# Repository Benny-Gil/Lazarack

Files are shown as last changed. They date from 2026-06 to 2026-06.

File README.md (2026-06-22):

# lazarack

*Lazarus + rack* — **raise a dead laptop motherboard from the e-waste pile into a rack-mounted homelab server.**


&nbsp;
&nbsp;
&nbsp;
&nbsp;

A **3D-printable, highly-modular 1U case** that turns a salvaged laptop
motherboard into a unit you can rack-mount in a **10-inch "mini" server rack**.
It's **parametric** — set your board's outline in one block and the whole
chassis reflows, so it fits **any laptop board that fits a 10" rack** (the
**Dell Inspiron 15-5558 / 5559** is the worked example here). Modeled in
**OpenSCAD**; every part prints flat with no supports on a low-accuracy
**Creality Ender 3 V3 SE** (220 × 220 mm bed) in PETG.

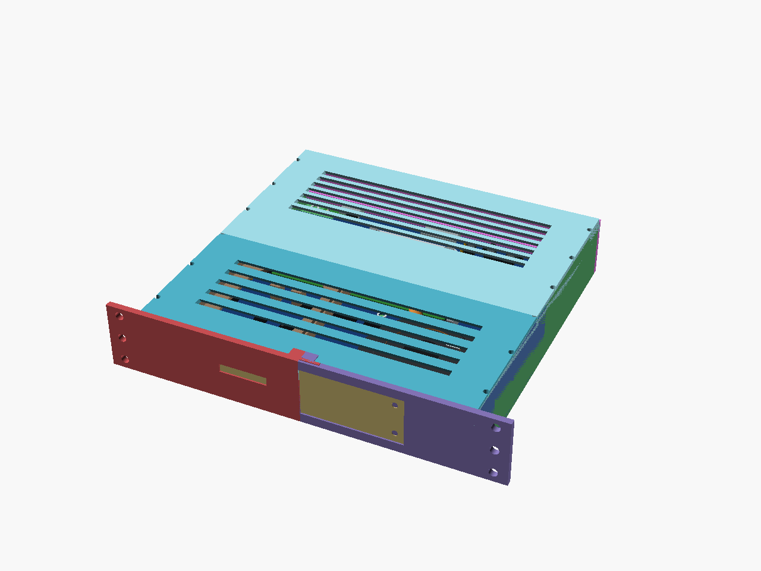
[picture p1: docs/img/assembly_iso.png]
Assembled, isometric


> ⚠️ **Work in progress.** The geometry is complete and renders/exports cleanly,
> but the board-specific dimensions in `parts/params.scad` are still **estimates
> tagged `// MEASURE`**. Caliper your board and update that one file before
> printing for real. See [Measuring your board](#measuring-your-board).

**Jump to:** [Design](#design-language--loose-fit-bolt-tight) · [Why](#why) · [How it goes together](#how-it-goes-together) · [Print it](#print-it) · [Build it](#build-it) · [Use it for another board](#use-it-for-a-different-board) · [Measuring your board](#measuring-your-board) · [License](#license)

---

## Design language — "loose-fit, bolt-tight"

This is a **Round-2 redesign** for a low-accuracy printer. The governing rule is
**LOOSE-FIT, BOLT-TIGHT**: nothing relies on a dimensionally accurate print to
mate. Every seam carries a `FIT_CLEARANCE` (0.5 mm) gap that absorbs print slop,
and **bolts pull the seams flush** rather than press-fit tolerances. Concretely:

- The baseplate is **four bed-friendly quadrants** bolted together by flat
  **seam-splice** bars across each seam — no tight interlocks to fight.
- The board is **not** held by fixed, dimensionally-critical standoffs. Instead
  it sits on **grid-placed `m25_grid_insert` standoffs** you drop onto the pilot
  grid wherever the board's holes land, and is trapped at the edges by
  **`board_edge_clip`** fingers. Slop in the print is taken up by the grid, not
  by a hole you have to hit exactly.
- Front `io_subplate` and `rear_panel` ship **blank** — you drill the actual
  port cutouts to your board after a test fit, so a misjudged dimension is a
  drill bit away, not a reprint.

---

## Why

A repurposed laptop motherboard makes a tidy, low-power homelab node — but it has
no chassis, odd mounting holes, split I/O, and (on this board) a **missing M.2
retention standoff**. This project wraps it in a bolt-together enclosure that
mounts to a [NiH DIY 10" cage-nut rack](https://www.printables.com/model/1634385-project-diy-10-server-rack)
and solves each of those problems with an independently-printable, swappable
module — none of which needs a precise print to work.

| Target | Detail |
|---|---|
| **Board** | Dell Inspiron 15-5558 / 5559 (Compal LA-B843P / LA-D071P), near-square ~203 × 197 mm |
| **Rack** | NiH "DIY 10-inch Server Rack" — EIA/ECA-310, **M5 cage nuts**, three 1U face holes per column |
| **Height** | **1U (44.45 mm)** — low-profile; board lies flat with its SODIMMs/blower under the lid |
| **Printer** | Ender 3 V3 SE (220 × 220 × 250 mm), low accuracy; every part ≤ ~190 mm/axis, flat, support-free |
| **Material** | PETG, 0.2 mm layer, 3–4 walls, 30–40 % infill |

---

## How it goes together

Everything bolts to **one shared 15 mm M3 self-tap pilot grid** on the
quadrant baseplate, so modules are independently printable, swappable, and
forgiving of print error.

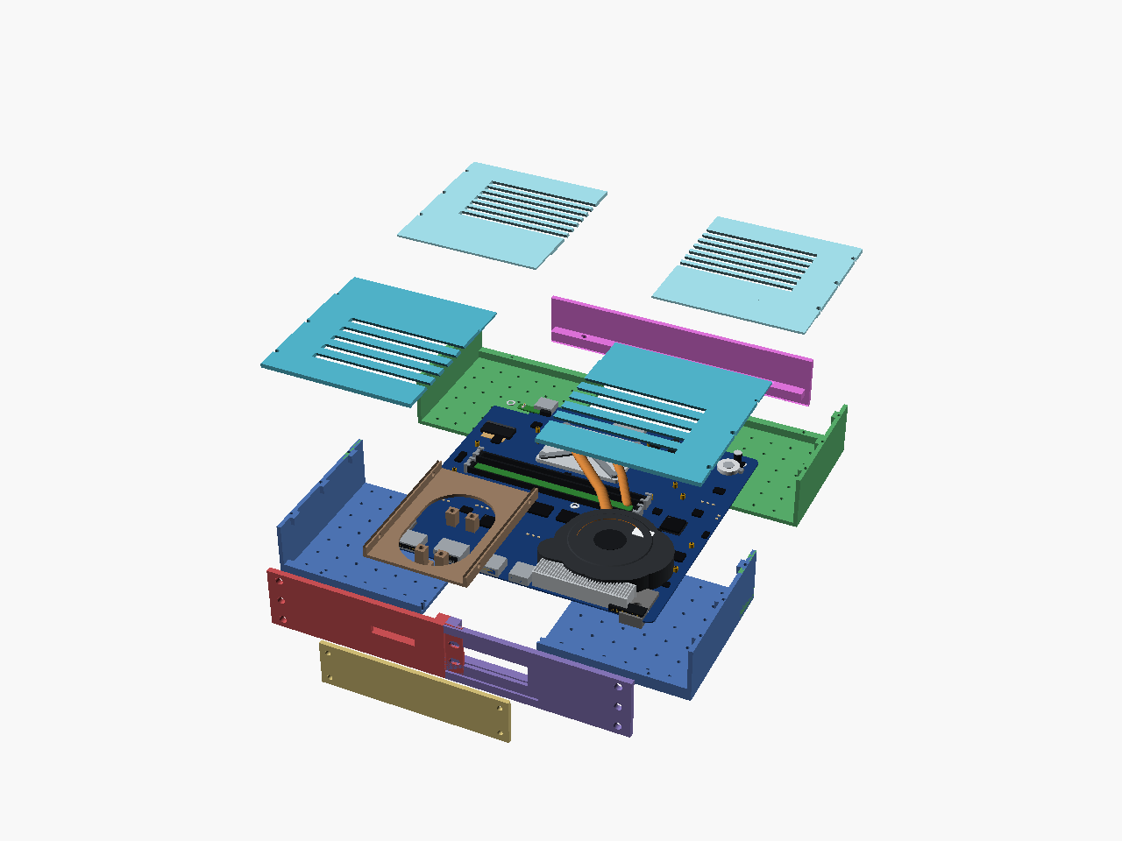
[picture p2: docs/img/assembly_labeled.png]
Exploded view with part legend


| # | Part | Role |
|---|---|---|
| 1–4 | `baseplate` → `baseplate_quad(qx,qy)` ×4 | Structural floor split into **four bed-friendly quadrants** with integral side walls; tied together by flat **`seam_splice`** bars bolted across the X and Y seams. Carries the 15 mm M3 self-tap pilot grid. |
| – | `seam_splice()` | Flat bridging bar that bolts across a quadrant seam into the grid (the "bolt-tight" half of the seam). |
| 5–6 | `faceplate_left` / `faceplate_right` | The 254 mm rack faceplate, split at the centerline (X=106) so each **M5 rack column stays whole on one tile**. Its bottom flange **rests on the front lip and bolts straight down** into shared self-tap pilots. |
| 7 | `io_subplate` | **Blank** swappable front insert with the 130 × 32 I/O window — you drill HDMI / USB-A / exhaust to your board after a fit check. |
| 8 | `m2_retainer` | Gusseted M2.5 post that **supplies the missing M.2 standoff**. |
| 9 | `rear_panel` | **Blank** rear panel — drill USB-C power-in / SD / audio later. Flange **rests on the rear lip and bolts into the shared pilots**. |
| 10 | `ssd_mezzanine` *(opt)* | 2.5" SATA drive carrier on stilts **above** the board, bolted to the grid. |
| 11–14 | `lid` → `lid_front(qx)` / `lid_rear(qx)` *(opt)* | Vented 1U top in **four bed-friendly tiles** (split in X *and* Y); each thumb-screws down into **wall-top self-tap bosses** on the baseplate. |
| – | `m25_grid_insert()` | Grid-dropped M2.5 board standoff (placed where the board holes land, not fixed). |
| – | `board_edge_clip()` | Finger that traps the board edge — board retention without a critical hole. |

With the lid off, the board drops onto grid-placed M2.5 standoffs, is trapped by
edge clips, and the I/O lines up behind the blank front subplate:

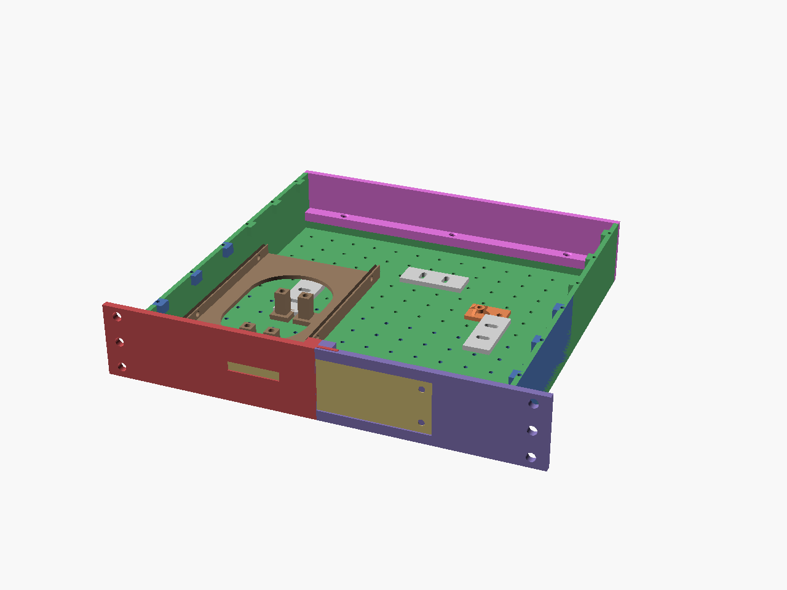
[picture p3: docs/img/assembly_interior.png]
Board mounted in the open chassis


The baseplate grid is **self-tapping pilot holes**, not a carpet of inserts —
you drive an M3 straight into the PETG only where a module (or standoff) lands:

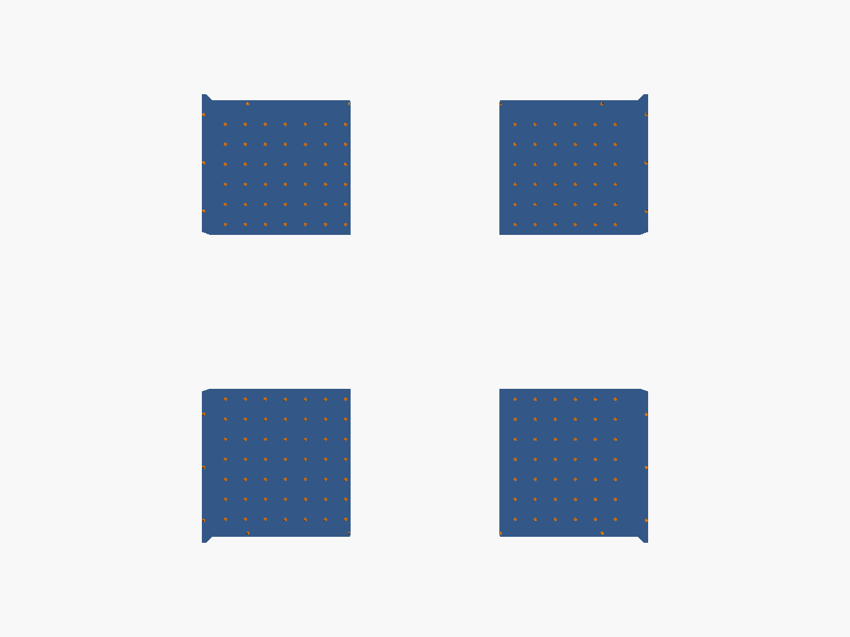
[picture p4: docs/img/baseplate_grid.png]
Baseplate self-tap pilot grid (one quadrant)


The four quadrants **butt together** and are tied by flat **`seam_splice`** bars
(red) that bolt into the grid on each side of a seam — slotted holes absorb
print slop, no interlock to fight:

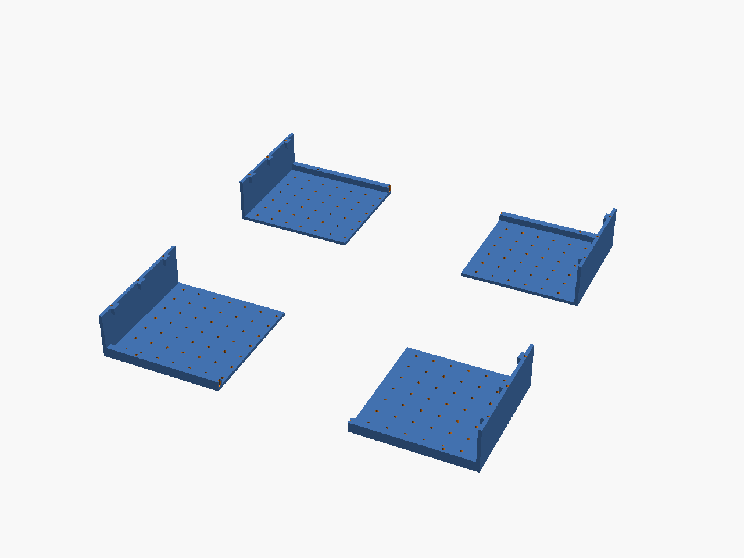
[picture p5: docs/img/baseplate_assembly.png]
Four baseplate quadrants joined by seam splices


Full mechanical spec, joinery, BOM, and print-plate layout: **[`CASE_DESIGN.md`](CASE_DESIGN.md)**.
Slicer settings (Ender 3 V3 SE · PETG): **[`SLICING.md`](SLICING.md)**.

---

## Print it

| | |
|---|---|
| **Filament** | ~**405 g** PETG (core) · ~**565 g** with the optional SSD mezzanine + lid — about **½ a 1 kg spool** |
| **Time** | ~**30–40 h** (core) · ~**45–55 h** (full set) at the guide's PETG speeds |
| **Settings** | PETG · 0.2 mm layer · 4 walls · ~30 % infill · **no supports** · **brim** |

Ready-to-slice STLs and the recommended **print order** live in **[`stl/`](stl/)**;
the full slicer profile (temps, retraction, tolerance settings) is in
**[`SLICING.md`](SLICING.md)**. Re-export after editing `params.scad` with
**`./export_stl.sh`**.

---

## Build it

Requires [OpenSCAD](https://openscad.org/) (2021.01+).

```bash
# View the whole assembly
openscad main.scad

# Export the full assembly to STL
openscad -o assembly.stl main.scad

# Export a single printable part
openscad -o faceplate_left.stl parts/faceplate_left.scad

# Export one baseplate quadrant
echo 'use <parts/baseplate.scad> baseplate_quad(0,0);' > q.scad
openscad -o quad.stl q.scad
```

`main.scad` knobs: `EXPLODE` (mm, for an exploded view), `SHOW_SSD`, `SHOW_LID`,
`SHOW_BOARD`, `SHOW_MOUNTS` (the illustrative grid standoffs + edge clips).

### Layout

```
main.scad                 top-level assembly (unions all parts, no transforms)
parts/params.scad         the frozen contract — ALL dimensions live here
parts/*.scad              one printable module per file
parts/reference_board.scad  visual-only board model (never printed)
lib/joinery.scad          reusable parametric joints (lap, grid, inserts, clips, …)
docs/img/                 rendered previews
reference-images/         photos of the donor board
```

---

## Use it for a different board

The Dell 15-5558/5559 is just the **worked example** — this case fits **any
laptop motherboard that fits a 10" rack**. The whole chassis auto-sizes from one
block at the top of `parts/params.scad`:

```scad
// ★★★  YOUR BOARD  —  THE ONLY SECTION YOU EDIT FOR A DIFFERENT BOARD  ★★★
BOARD_W_X = 203;   // board WIDTH  (X) = the rack-facing / I-O edge   // EDIT
BOARD_D_Y = 197;   // board DEPTH  (Y) = I/O edge to the back         // EDIT
BOARD_T   = 1;     // board thickness                                // EDIT
STANDOFF_H = 5;    // standoff height under the board (tallest part)  // EDIT
```

Change those four numbers and the **body width, interior depth, the four
baseplate quadrants, the faceplate centering, and the M3 grid all reflow
automatically** — no other file to touch. You don't need exact hole or port
positions: the board rides on **grid-placed standoffs + edge clips** (any hole
pattern) and the **blank** front/rear panels are **drilled to fit**.

**It must fit a 10" rack.** Built-in `assert`s stop the build with a clear
message if the board is too big — practical limits are about **≤ 207 mm wide**
(to clear the rack rails) and **≤ ~237 mm deep**. Boards larger than that need a
deeper/wider rack, not this case.

> Heads-up: the baseplate and lid are split into bed-friendly tiles, but the
> one-piece **`rear_panel`** is full body-width — near the 207 mm-wide max it
> pushes the 220 mm bed edge, so print it with a brim (or split it like the rest).

---

## Measuring your board

Once you've set the outline above, anything tagged `// MEASURE` in
`parts/params.scad` should be calipered and corrected before a real print. Note
that the loose-fit design tolerates small errors — and the **blank** io_subplate
and rear_panel are **drilled to fit after assembly**, so port positions are the
least critical of all:

1. PCB length × width (near-square ~203 × 197 mm) and the mounting-hole positions
2. M.2 connector position + retainer distance + your card length (2242/2260/2280)
3. Blower exhaust outlet size + position (drilled into the io_subplate)
4. Front port positions (HDMI, USB-A ×2) and rear (USB-C, SD, audio) — drilled later
5. SODIMM + blower seated height (confirms the 1U lid clears)

Edit **only** `parts/params.scad` — every part derives from it.

The donor board this was designed around — and the recognizable OpenSCAD
reference model (`parts/reference_board.scad`, visual-only) built from it that
appears in the renders above:

<table>
  <tr>
    <th align="center">Donor board (photo)</th>
    <th align="center">Reference model (OpenSCAD)</th>
  </tr>
  <tr>
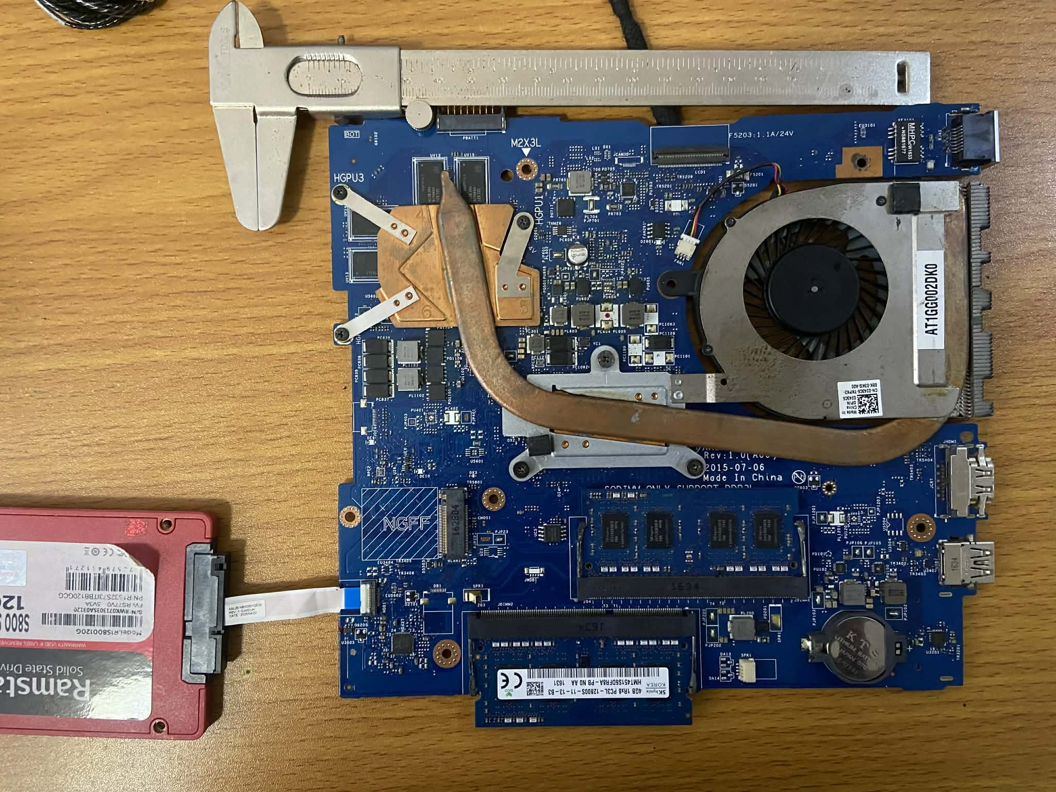
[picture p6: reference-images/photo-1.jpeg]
Donor Dell 5558 motherboard
    <td align="center"></td>
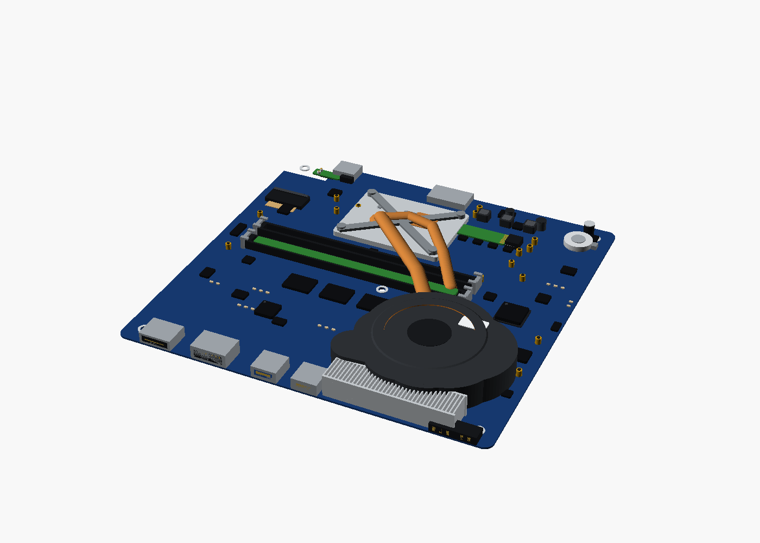
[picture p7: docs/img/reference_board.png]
OpenSCAD reference board model
    <td align="center"></td>
  </tr>
</table>

---

## License

[MIT](LICENSE) © 2026 Benny Gil. The Dell board and the NiH rack are referenced
for fit only and are the property of their respective owners.

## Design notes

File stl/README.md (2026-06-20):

# Printable STLs

Exported, ready-to-slice parts for the 1U case. **Regenerate after you edit
`parts/params.scad`** (e.g. once you caliper the board):

```bash
./export_stl.sh        # from the repo root
```

> ⚠️ These are **prototype** exports from the `// MEASURE` placeholder
> dimensions in `params.scad`. Re-export once you've measured the board.
> `reference_board.scad` is a visual prop and is **not** exported.

## Print settings (Ender 3 V3 SE, low-accuracy)

PETG · 0.2 mm layer · 4 walls · ~30 % infill · **no supports** · **brim**
(the design is "loose-fit, bolt-tight", so a brim + the FIT_CLEARANCE gaps
absorb dimensional slop). All parts print **flat, largest face down**.

**Full slicer profile — temps, retraction, tolerance settings, per-part notes:
see [`../SLICING.md`](../SLICING.md).**

**Filament:** ~**405 g** PETG for the core case (~40 % of a 1 kg spool),
~**565 g** for the full set incl. SSD mezzanine + lid. Breakdown in
[`../SLICING.md`](../SLICING.md#filament-estimate-petg-127-gcm³).

## Print order

Print **bottom-up / structure-first**, and validate fit on a small cheap part
before committing to the big ones:

| # | Part(s) | Qty | Notes |
|---|---|---|---|
| 0 | `board_edge_clip` **or** `m25_grid_insert` | 1 | **Print this first** — a 5-min part to dial in your printer + the slot/peg fit before the big prints. |
| 1 | `baseplate_FL` `baseplate_FR` `baseplate_RL` `baseplate_RR` | 1 each | The structural floor. One quadrant per plate (~106 × 110 mm). |
| 2 | `seam_splice` | ~6 | Tiny bars that bolt the quadrants together — batch several per plate. |
| 3 | `m25_grid_insert` | ~5 | Board standoffs (place at the grid points nearest your board's holes). |
| 4 | `board_edge_clip` | ~4 | Board edge hold-downs. Batch with the inserts/splices. |
| 5 | `faceplate_left` `faceplate_right` | 1 each | Front rack faceplate (cage-nut to the rails). |
| 6 | `rear_panel` | 1 | Blank closure (drill USB-C/SD/audio after a fit check). |
| 7 | `m2_retainer` | 1 | Supplies the missing M.2 standoff. |
| 8 | `io_subplate` | 1 | Blank front insert (drill HDMI/RJ45/USB/exhaust after fit, then reprint just this part). |
| 9 | `ssd_mezzanine` | 1 | *Optional* — only if mounting a 2.5" SATA SSD. |
| 10 | `lid_front` `lid_rear` | 1 each | *Optional* vented top. |

Steps 2–4 are small and can share one build plate. Steps 9–10 are optional.

## Assembly (quick)

1. Bolt the 4 quadrants together with `seam_splice` bars into the grid.
2. Drop `m25_grid_insert` standoffs at the grid points nearest the board's
   holes; set the board on them; add `board_edge_clip`s to trap the edges.
3. Bolt on `m2_retainer`, then the faceplates (front) and rear panel.
4. Drill + fit `io_subplate` to your real port positions; add the optional
   `ssd_mezzanine` and `lid`.
5. Cage-nut the faceplate to the 10" rack front rails (M5, 236.525 mm spacing).

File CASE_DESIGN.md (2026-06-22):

# Modular Laptop Motherboard Server Case — Design Spec

A 3D-printed **1U** enclosure that mounts a salvaged **laptop motherboard**
into a **NiH "DIY 10-inch" cage-nut server rack** (Printables #1634385). It is
**parametric**: set your board's outline in the `★ YOUR BOARD` block of
`parts/params.scad` and the body width, interior depth, the four baseplate
quadrants, faceplate centering, and the grid all reflow — so it fits **any
laptop board that fits a 10" rack** (the **Dell Inspiron 15-5558/5559** is the
worked example, and `assert`s stop the build if a board is too big). All
structural parts print on a **low-accuracy Creality Ender 3 V3 SE**
(bed 220 x 220 x 250 mm) in **PETG**, flat, with no supports.

The full parametric model lives in `parts/*.scad` (one module per printed
part), shares one frozen contract in `parts/params.scad`, and is joined by
the reusable joinery library in `lib/joinery.scad`. `main.scad` unions all
parts with no transforms.

---

## Design language — LOOSE-FIT, BOLT-TIGHT

This is the **Round-2 redesign**, retargeted at a printer that cannot be
trusted to hit dimensions. The single governing principle:

> **Nothing relies on a dimensionally accurate print to mate. Gaps absorb
> slop; bolts pull seams flush.**

Every mating seam carries `FIT_CLEARANCE = 0.5 mm` of deliberate gap. Seams
are not press-fit interlocks — they are **bolted** flush with `seam_splice`
bars and grid screws. The board is held by **grid-placed standoffs and edge
clips**, not by fixed standoffs that demand a hole hit exactly. The front
and rear panels ship **blank** and are **drilled to the real board after a
test fit**. The result: a misjudged dimension costs a drill bit or a
relocated standoff, never a reprint.

---

## Board Analysis

| Parameter | Value |
|---|---|
| Board | Dell Inspiron 15-5558 / 5559 motherboard |
| Footprint | **near-square ~203 mm (X) x 197 mm (Y) x ~1 mm** |
| Fan | Blower (side), heatpipe-fed |
| Front I/O (Edge-alpha) | HDMI + USB-A x2 + blower **exhaust** (drilled into io_subplate) |
| Rear I/O (Edge-beta) | USB-C power-in (barrel jack replaced) + SD reader + 3.5 mm audio |
| Storage | NGFF (M.2) onboard + SATA to a 2.5" SSD on the mezzanine |
| Mounting | corner + center holes; **M.2 standoff is missing** (added by a printed retainer). Board held by grid-placed M2.5 standoffs + edge clips, not fixed posts |

> Every uncertain real-world dimension is a `// MEASURE` placeholder in
> `params.scad` with a sane default, so the model renders today. Caliper the
> board and edit **only `params.scad`**. Because the panels are drilled to
> fit, port positions are the most forgiving numbers in the file.

---

## Target Form Factor — 1U, 10" rack

| Dimension | Value |
|---|---|
| Rack standard | NiH DIY 10" cage-nut rack (Printables #1634385) |
| Height | **1U = 44.45 mm** (`EXT_HEIGHT`); side walls `UPSTAND_H` = 40 mm, faceplate panel `FACE_H` = 43.66 mm |
| Structural body width | `BODY_W` = 212 mm (X: 0..212), centerline `BODY_CX` = 106 |
| Interior depth | `DEPTH` = 210 mm |
| Faceplate width | `FACE_W` = 254 mm (full rack width, X -21..233) |
| Rack fasteners | **M5** cage-nut clearance holes; three 1U face holes per column at Z = 6.35 / 22.225 / 38.1 mm (`EIA_FACE_HOLES_Z`) |

### Shared assembly coordinate frame
Origin `(0,0,0)` = **front-bottom-left interior corner** of the chassis.
`+X` width (left->right), `+Y` depth (front->rear, Y=0 is the rack-front
interior face), `+Z` height (bottom->top). Every part is modeled directly
in this frame; `main.scad` does no transforms. The board PCB underside sits
at `BOARD_Z` = 8 mm (`FLOOR` 3 + `STANDOFF_H` 5).

---

## The Printed Parts

| # | File / module | Role |
|---|---|---|
| 1–4 | `baseplate.scad` -> `baseplate_quad(qx,qy)` (×4) | Structural floor split into **four bed-friendly quadrants** (qx,qy ∈ {0,1}), each with its integral side/floor walls and its share of the 15 mm M3 self-tap pilot grid. No fixed standoffs. |
| – | `baseplate.scad` -> `seam_splice(span)` | Flat bar that bolts **across** a quadrant seam into the grid on both sides — the "bolt-tight" element that pulls a loose seam flush. |
| 5 | `faceplate_left.scad` -> `faceplate_left()` | Left half of the 254 faceplate; whole **left M5 rack column** (`M5_X_LEFT`); left half of the io-window. Split at `FACE_SPLIT_X` = 106. |
| 6 | `faceplate_right.scad` -> `faceplate_right()` | Right half; whole **right M5 column** (`M5_X_RIGHT`); right half of the io-window. |
| 7 | `io_subplate.scad` -> `io_subplate()` | **Blank** swappable front insert (`IO_SUB_W` 130 x `IO_SUB_H` 32 x `IO_SUB_T` 3) filling the faceplate window. Ports (HDMI / USB-A / exhaust) are **drilled by the user** after a fit check. |
| 8 | `m2_retainer.scad` -> `m2_retainer()` | Gusseted M2.5 post supplying the **missing M.2 standoff**; foot bolts to the grid, top takes an M2.5 insert. |
| 9 | `rear_panel.scad` -> `rear_panel()` | **Blank** rear panel (`REAR_W` 212 x `REAR_H` 40 x `REAR_T` 4). Flange **rests on the rear lip and bolts down into the shared pilots**; USB-C / SD / audio cutouts **drilled later**. |
| 10 | `ssd_mezzanine.scad` -> `ssd_mezzanine()` *(opt)* | 2.5" SATA drive carrier on stilts **above** the board, bolted to the grid (keeps the floor clear). |
| 11–14 | `lid.scad` -> `lid_front(qx)`, `lid_rear(qx)` *(opt)* | Vented **1U** top in **four bed-friendly tiles** (split in X *and* Y); each thumb-screws down into **wall-top self-tap bosses** the baseplate provides. |
| – | `m25_grid_insert.scad` -> `m25_grid_insert(h)` | Grid-dropped M2.5 board standoff — placed wherever the board's holes land on the pilot grid. The tolerance-first replacement for fixed standoffs. |
| – | `board_edge_clip.scad` -> `board_edge_clip(reach)` | Finger that reaches over and traps the board edge — board retention that needs no precise hole. |

Every part fits within the ~190 mm print limit in both bed-plane axes and
prints largest-face-down with no supports.

---

## Joinery & the Common M3 Grid Interface

The single interoperability standard is **one 15 mm-pitch M3 self-tap pilot
grid** (`GRID_PITCH` 15, origin `GRID_X0`/`GRID_Y0` = 12.5, pilots Ø`GRID_PILOT_D`
2.5 x `GRID_PILOT_DEPTH` 2.4 mm) on the quadrant floors. The grid points are
blind pilot holes you screw an M3 directly into (PETG self-taps) — **no
heat-set inserts in the grid**, and the floor stays flat. Everything bolts to
this grid: the seam splices, the M.2 retainer, SSD mezzanine, board standoffs
(`m25_grid_insert`), edge clips. You only tap the few points each item
actually uses.

The loose-fit/bolt-tight rule means seams **never** depend on an accurate
print. Each seam has a `FIT_CLEARANCE` (0.5 mm) gap and is closed by a bolted
element rather than an interference fit. `CHAMFER` (0.8 mm) breaks edges so
parts self-locate as bolts draw them together.

Reusable joints live in `lib/joinery.scad` (parametric — they take explicit
args, they do not read `params.scad`):

| Joint | Where used |
|---|---|
| `rabbet_lap_male` / `rabbet_lap_female` | Quadrant/lid seams where a stepped lap helps the splice register |
| `dovetail_male` / `dovetail_female` | Optional registration on the faceplate centerline seam |
| `dowel_hole` | Alignment pins / the blind pilot-grid bores |
| `tongue` / `groove` | Panel-bottom flanges into baseplate lips |
| `heatset_boss` | Structural seam/module joints (bores open **upward**, no bridging) |
| `m3_grid` | The 15 mm self-tap grid stamped into each quadrant floor |
| `m25_standoff` / `m25_grid_insert` | Board standoffs + M.2 post top, dropped on grid points |
| `eia_face_holes` | M5 rack clearance holes through the faceplate (three 1U Z positions) |
| `louver_grille` | Louvered vents in the lid tiles |

**Printability rules enforced in geometry:** every part lies flat,
largest-face-down, zero supports; no overhang > 45 deg without a
chamfer/teardrop; all heat-set bores open upward; base fillets/gussets on
side-loaded posts.

---

## Resolved I/O Mapping

```
            FRONT faceplate (Edge-alpha)          REAR panel (Edge-beta)
        ┌──────────────────────────────┐      ┌──────────────────────────────┐
        │  io_subplate window (BLANK):  │      │  rear_panel (BLANK):          │
        │   HDMI            ← drilled    │      │   USB-C power-in  ← drilled   │
        │   USB-A x2        ← drilled    │      │   SD card reader  ← drilled   │
        │   blower EXHAUST  ← drilled    │      │   3.5 mm audio    ← drilled   │
        └──────────────────────────────┘      └──────────────────────────────┘
```

- Both panels ship **blank**. After a test fit of the real board you mark and
  **drill** each cutout — the loose-fit philosophy applied to I/O: you never
  have to predict a port position to sub-millimeter and reprint if wrong.
- **Front** carries the user-facing data ports plus the blower exhaust via the
  swappable `io_subplate`.
- **Rear** carries power-in and the low-traffic ports.

### Airflow
Blower intake is internal; the exhaust is **drilled** into the front
io_subplate aligned to the fan outlet (`EXHAUST_POS` / `EXHAUST_SIZE`, both
`// MEASURE`). Vented lid tiles assist; no active case cooling — the laptop
fan handles it.

### Power
The barrel jack was replaced with **USB-C power-in** drilled into the rear
panel (`USBC_POS` / `USBC_SIZE`, `// MEASURE`).

---

## Ender 3 V3 SE Print Plate

PETG, **0.2 mm** layer, **3-4 walls**, **30-40% infill**, **no supports**,
**brim** recommended for the tall thin faceplate/rear tiles. Every part
prints flat (largest face down). The four small **quadrants** each fit the
bed comfortably and are forgiving of warp because the splices, not tight
interlocks, register the seams.

| Part | Orientation on bed | Notes |
|---|---|---|
| `baseplate_quad` ×4 | floor-down | Grid bores face up; one or two quads per plate |
| `seam_splice` | flat | Tiny; batch several per plate |
| `faceplate_left` / `faceplate_right` | outer face down | Brim; M5/window features need no support laid flat |
| `io_subplate` | back face down | Ships blank — drill ports after fit |
| `rear_panel` | outer face down | Brim; ships blank — drill ports after fit |
| `m2_retainer` | foot down | Gussets print in-plane; M2.5 bore opens up |
| `ssd_mezzanine` *(opt)* | floor down | Stilts print up |
| `lid_front(qx)` / `lid_rear(qx)` *(opt)* | flat | 4 tiles (X+Y split); vent slots in-plane |

---

## Bill of Materials

### Printed parts (PETG)
| Part | Qty |
|---|---|
| baseplate_quad | 4 |
| seam_splice | ~4 (one per seam, batch spares) |
| faceplate_left, faceplate_right | 1 each |
| io_subplate (blank) | 1 |
| m2_retainer | 1 |
| rear_panel (blank) | 1 |
| m25_grid_insert (board standoffs) | ~5 (one per board hole) |
| board_edge_clip | ~4 |
| ssd_mezzanine *(optional)* | 1 |
| lid_front(qx), lid_rear(qx) *(optional)* | 2 each (qx = 0 left / 1 right) = 4 tiles |

### Fasteners & hardware
| Item | Qty (approx) | Use |
|---|---|---|
| M3 brass heat-set inserts (bore ~4.0 mm x 5 mm) | ~12-18 | Structural seam bosses only — **grid uses no inserts** |
| M3 screws (8-10 mm) | ~30-40 | Seam splices, panels, mezzanine, retainer, clips — self-tap into the grid |
| M2.5 brass heat-set inserts | ~6 | Board standoff tops (`m25_grid_insert`) + M.2 post |
| M2.5 screws | ~6 | Board hold-down + M.2 retainer |
| M5 rack cage nuts + screws | up to 6 | Three 1U face holes per column (clearance, not inserts) |
| 2.5" SATA SSD *(optional)* | 1 | Mounted on ssd_mezzanine |

> Counts are upper-bound estimates; final counts depend on which optional
> parts you print and on the resolved `// MEASURE` board-hole positions
> (which decide how many `m25_grid_insert` standoffs and clips you place).

---

## Assembly Order

1. Heat-set M3 inserts into the **seam** bosses only; M2.5 inserts into the
   standoff/retainer tops. The grid needs no inserts — self-tap M3 only where
   something lands.
2. Lay out the **four baseplate quadrants** and pull each seam flush with a
   bolted **`seam_splice`** bar into the grid (loose-fit gaps close under the
   bolts).
3. Test-fit the board. Drop **`m25_grid_insert`** standoffs onto the grid
   points nearest each board hole, and add **`board_edge_clip`** fingers to
   trap the edges. Install the **m2_retainer** under the M.2 module.
4. Bolt the two **faceplate** tiles to the front quadrants (each keeps a whole
   M5 column).
5. Drop the **blank io_subplate** into the faceplate window; with the board
   present, **mark and drill** the front port + exhaust cutouts.
6. Fit the **blank rear_panel**; mark and **drill** USB-C / SD / audio to the
   board.
7. *(Optional)* Bolt the **ssd_mezzanine** to the grid above the board and
   install the SSD.
8. *(Optional)* Add the two vented **lid** tiles.
9. Bolt into the 10" rack with M5 cage nuts (whole left/right columns, three
   1U holes each).

---

## Notes / Next Steps

- **Caliper before printing the final run** — edit only `params.scad`:
  board hole positions, M.2 connector + retainer distance, the exhaust/port
  positions you'll drill, and the rack-datum vs chassis-floor offset.
- **Confirm the EIA face-hole Z list** (`EIA_FACE_HOLES_Z` = 6.35 / 22.225 /
  38.1) lines up with the physical 1U rack U-grid before committing the
  faceplate.
- **Verify USB-C power-in** wiring/handshake for the replaced barrel jack.
- The legend-labeled render (`docs/img/assembly_labeled.png`) is from an
  earlier revision and is **stale**; the unlabeled iso/exploded renders are
  current.
- STL/PNG outputs are gitignored — only the `.scad` sources are committed.

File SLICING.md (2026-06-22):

# Slicing guide — Ender 3 V3 SE · 0.4 mm nozzle · PETG

Tuned for this case's **loose-fit, bolt-tight** design (brim, no supports, and
the tolerance lives in the model via `FIT_CLEARANCE = 0.5 mm`, not the slicer).
Field names are Cura-style; OrcaSlicer / Creality Print have the same settings.

> Print everything **flat, largest face down** (the STLs are already oriented).
> See [`stl/README.md`](stl/README.md) for the print order.

## Filament estimate (PETG, ~1.27 g/cm³)

Estimated from the exported STL volumes. It's a near-solid estimate (these parts
are mostly walls), so it runs a touch **high** — at 30 % infill expect ~10 % less.
**Slice for the exact number.**

| Part | g each | qty | g total |
|---|---:|---:|---:|
| `baseplate_FL` / `FR` (front) | ~64 | 2 | ~128 |
| `baseplate_RL` / `RR` (rear) | ~59 | 2 | ~117 |
| `seam_splice` | ~2.2 | 6 | ~13 |
| `faceplate_left` | ~34 | 1 | ~34 |
| `faceplate_right` | ~26 | 1 | ~26 |
| `rear_panel` | ~58 | 1 | ~58 |
| `io_subplate` | ~16 | 1 | ~16 |
| `m2_retainer` | ~1 | 1 | ~1 |
| `m25_grid_insert` | ~0.2 | 5 | ~1 |
| `board_edge_clip` | ~3 | 4 | ~12 |
| **Core (required) subtotal** | | | **~405 g** |
| `ssd_mezzanine` *(opt)* | ~24 | 1 | ~24 |
| `lid_front` / `lid_rear` *(opt)* | ~68 | 2 | ~135 |
| **Full set** | | | **~565 g** |

- **Core case ≈ 405 g** (+~5 % brim ≈ **425 g**) — about **40 %** of a 1 kg spool.
- **Full set (with SSD mezzanine + lid) ≈ 565 g** (≈ **55 %** of a spool).
- Biggest items: the **4 baseplate quadrants (~245 g)** and the **lid (~135 g)** —
  drop the optional lid/mezzanine and you're under half a spool.

### Print time (rough)

At the moderate speeds below (~45 mm/s outer walls), wall-heavy PETG parts run
~**10–14 g/hr** effective. **Slice for the exact number.**

| | Filament | Approx. time |
|---|---:|---:|
| **Core case** (required) | ~405 g | **~30–40 h** |
| **Full set** (+ mezzanine + lid) | ~565 g | **~45–55 h** |

- ≈ **2–2.5 days** of continuous printing for everything; ~1.5 days for the core.
- The **4 baseplate quadrants dominate** (~5–7 h each ≈ 24 h) — their tall walls
  print slowly. The small parts (splices/clips/inserts/io) are a few hours batched.
- These speeds are conservative; the V3 SE handles 80–100 mm/s, which cuts the
  total **~30–40 %** (at some quality cost on PETG).

## Material & temperature (PETG)

| Setting | Value |
|---|---|
| Nozzle temp | **240 °C** (235–245) |
| Bed temp | **75 °C** (70–80) |
| First-layer nozzle / bed | **245 °C / 80 °C** |
| Flow / extrusion multiplier | **0.95–1.0** — calibrate; PETG over-extrudes easily and that's what closes up holes/slots |

## Quality

| Setting | Value |
|---|---|
| Layer height | **0.2 mm** (0.24 OK for the chunky baseplates) |
| Initial layer height | **0.24 mm** |
| Line width | 0.4 mm |
| Walls / perimeters | **4** (1.6 mm — the 3 mm walls print fully solid) |
| Top / bottom layers | **5** |
| Infill | **30 %**, gyroid or grid |

## Speed (moderate — PETG on an open frame)

- Outer wall **45 mm/s**, inner 60, infill 70
- **First layer 20–25 mm/s** (adhesion). Don't chase the V3 SE's top speed on PETG.

## Cooling · retraction · adhesion

| Setting | Value |
|---|---|
| Fan | **40–50 %** (0 % for the first 2–3 layers) — PETG bond suffers if over-cooled |
| Retraction (Sprite **direct drive**) | **~1.0 mm @ 40 mm/s** (not Bowden's 5–6 mm) |
| Z-hop | 0.2 mm (optional; PETG oozes) |
| **Build-plate adhesion** | **Brim, 6–8 mm** — non-negotiable for the baseplate quads + 212 mm panels |
| **Supports** | **OFF** — everything is designed support-free |
| Z-seam | Rear / sharpest corner |

## ★ Design-specific settings (these matter most)

| Setting | Value | Why |
|---|---|---|
| Horizontal expansion / XY size compensation | **0** | `FIT_CLEARANCE` already builds the slop in — don't double it. |
| Hole horizontal expansion | **0** | Self-tap pilots *want* to print slightly undersized (tighter M3 bite); clearance holes are already oversized. |
| Elephant-foot / initial-layer horizontal expansion | **0** (or −0.15 mm) | A 0.8 mm bottom chamfer is built into the parts; add negative comp only if first layers still squish wide. |

## Per-part notes

- **Baseplate quadrants** — brim on, slow first layer, **one per plate**. Tallest /
  most warp-prone parts (a 40 mm wall on a 106 × 110 floor).
- **Rear panel + lid tiles (212 mm wide)** — brim, and watch the corners: at 212 mm
  they sit near the bed edge where adhesion/warp is worst. Clean bed + slow first layer.
- **Splices / clips / inserts** — batch several per plate; a small brim is plenty.
- **PETG + PEI plate** — the V3 SE's PEI sheet can grip PETG *too* hard and tear it.
  A thin **glue-stick layer acts as a release agent** (counterintuitive, but it
  protects the plate and pops parts off clean).

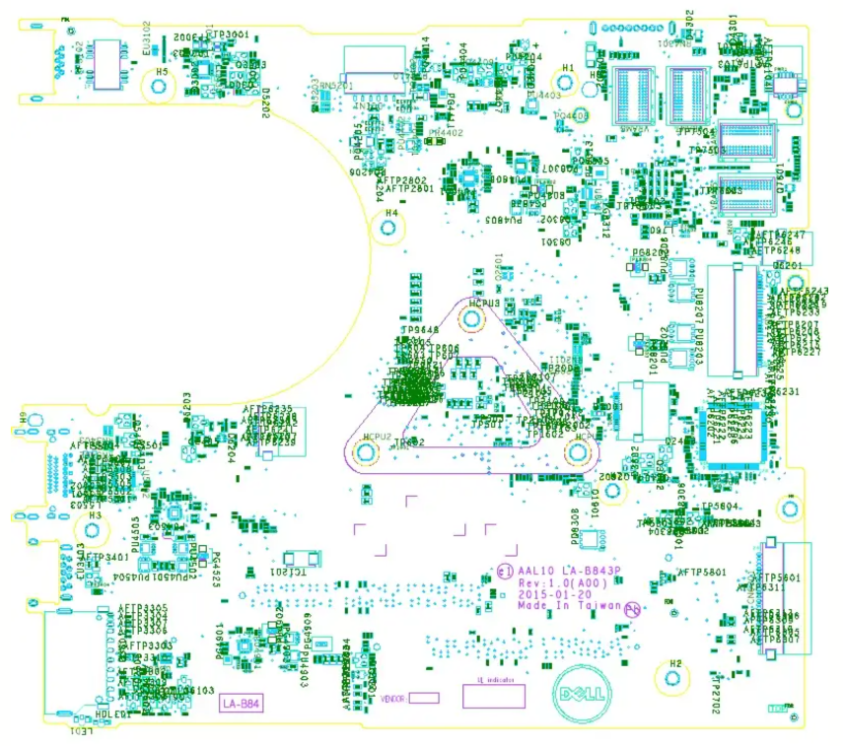
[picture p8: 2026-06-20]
reference-images/boardview-2.png

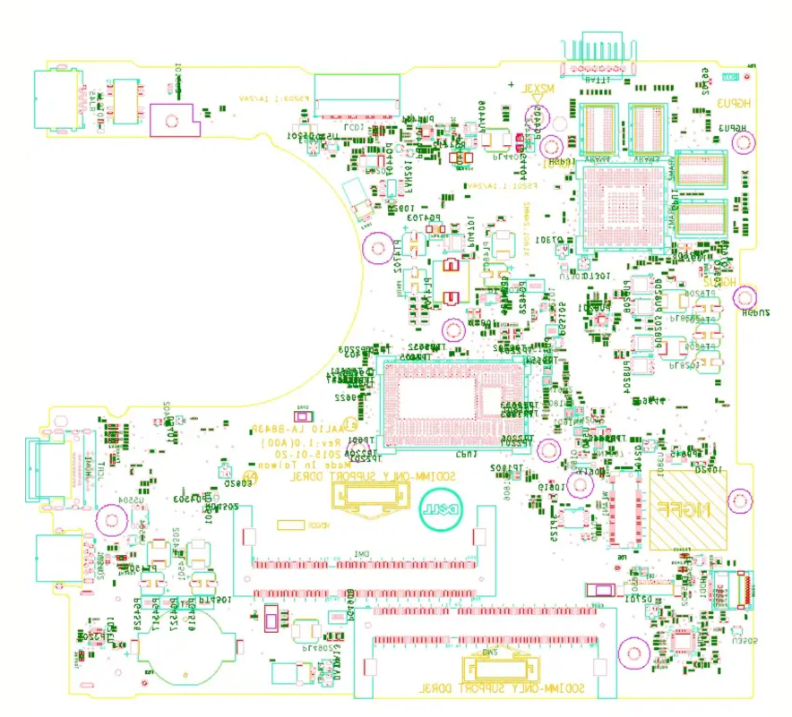
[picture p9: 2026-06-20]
reference-images/boardview-1.png

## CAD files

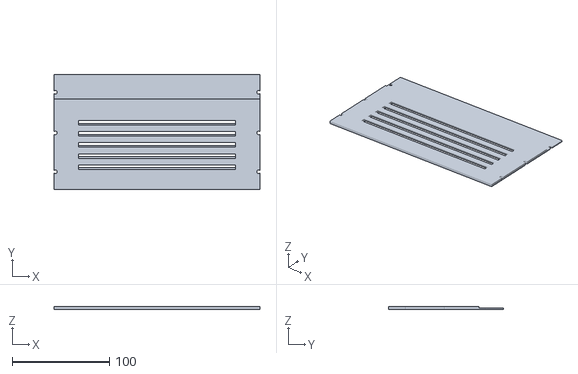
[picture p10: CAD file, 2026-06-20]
stl/lid_front.stl
212.0 x 118.0 x 3.00

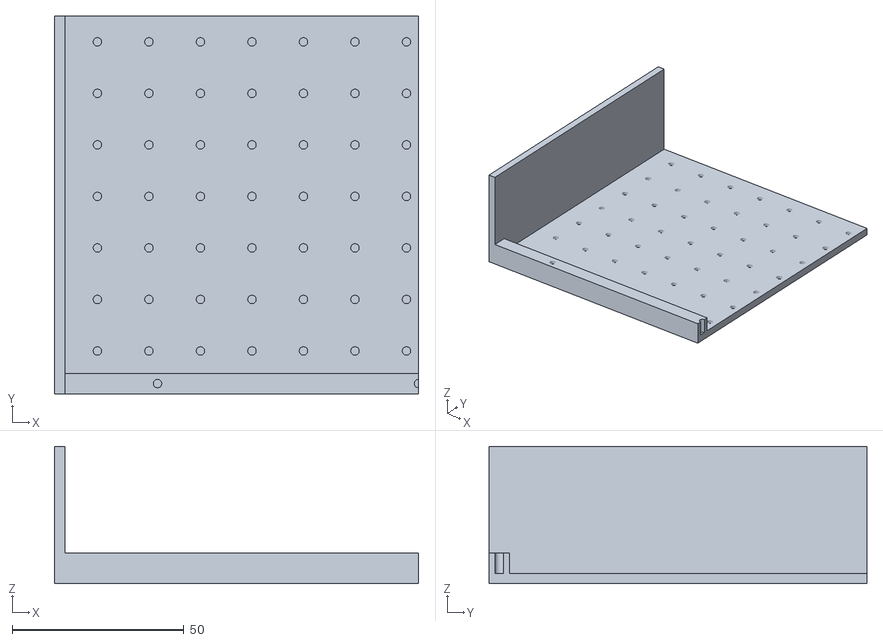
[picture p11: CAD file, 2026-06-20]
stl/baseplate_FL.stl
106.0 x 110.0 x 40.0

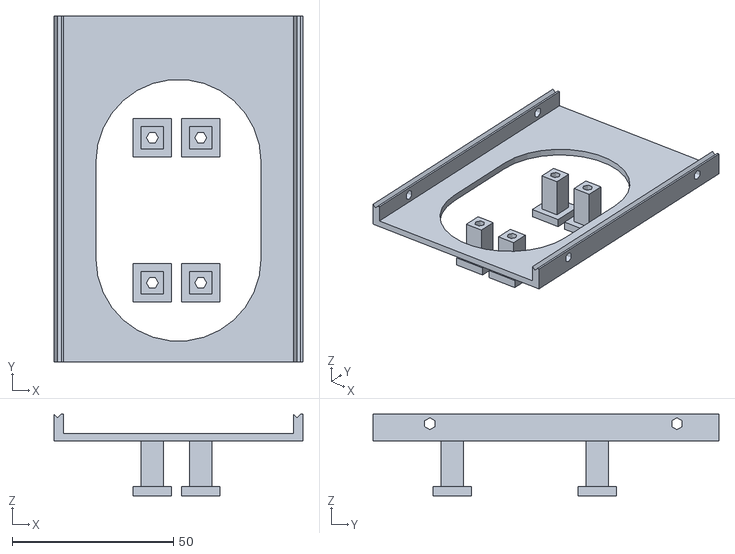
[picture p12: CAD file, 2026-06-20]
stl/ssd_mezzanine.stl
77.2 x 107.2 x 25.4

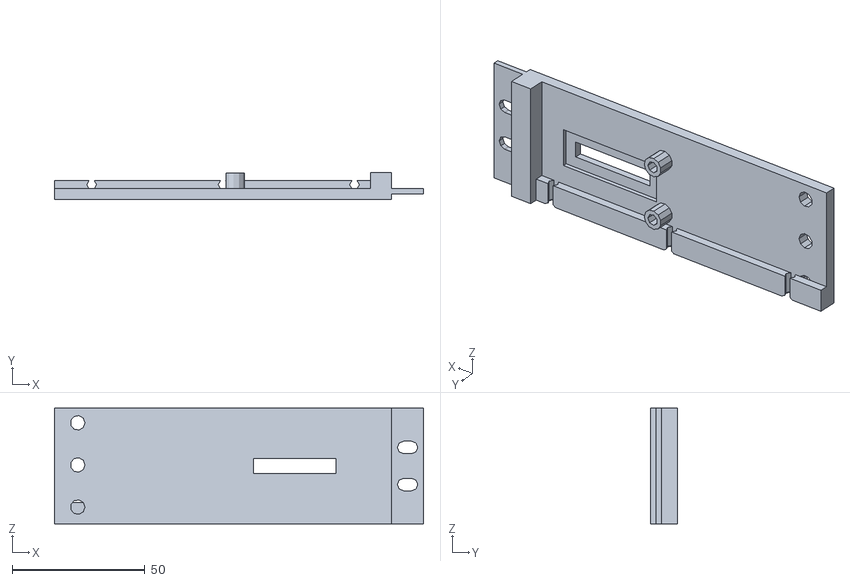
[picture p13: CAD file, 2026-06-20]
stl/faceplate_left.stl
139.0 x 10.0 x 43.7

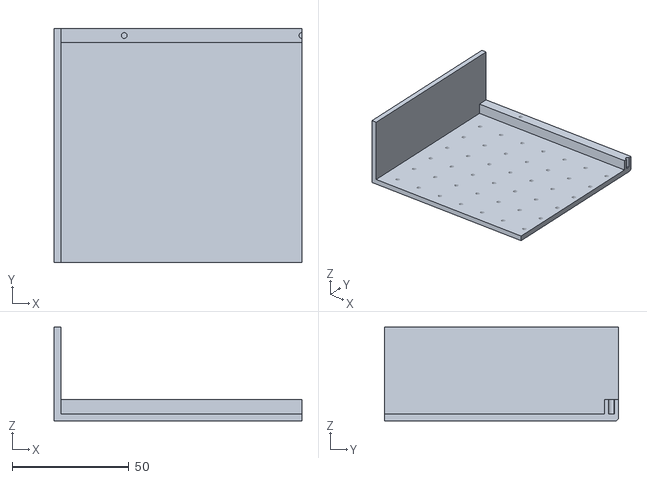
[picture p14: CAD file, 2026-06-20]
stl/baseplate_RL.stl
106.0 x 100.0 x 40.0

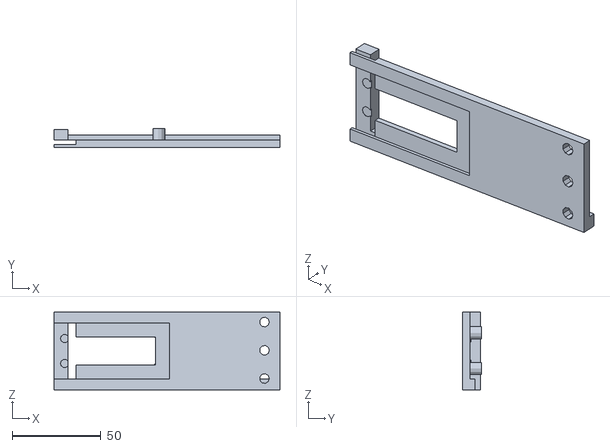
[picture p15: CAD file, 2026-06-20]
stl/faceplate_right.stl
127.0 x 10.5 x 43.7

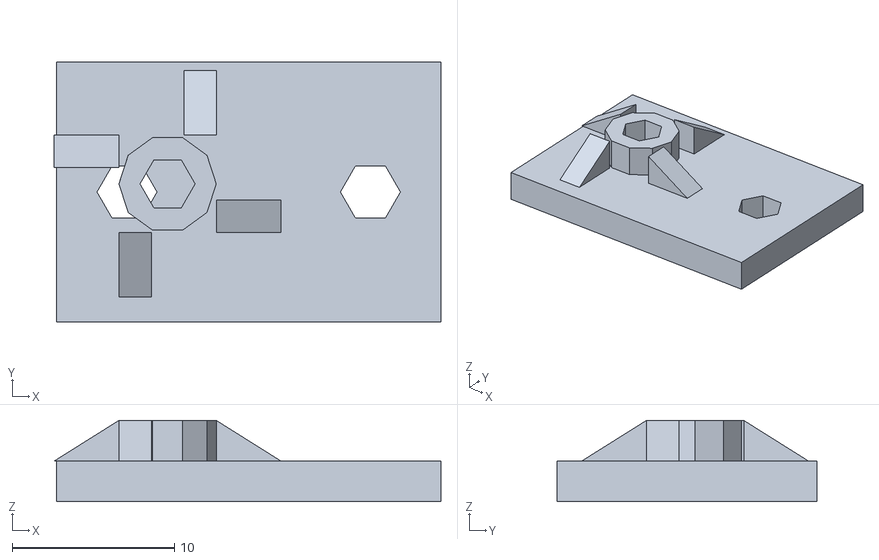
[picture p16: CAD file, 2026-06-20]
stl/m2_retainer.stl
23.8 x 16.0 x 5.00

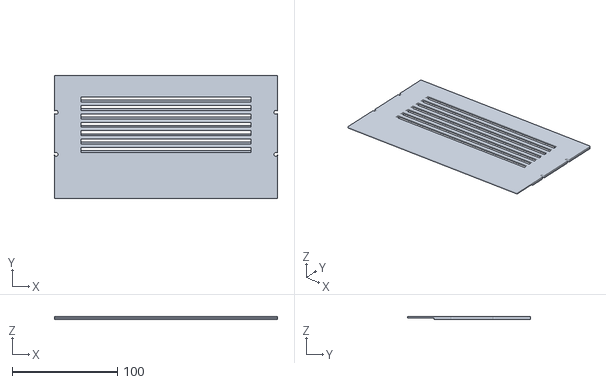
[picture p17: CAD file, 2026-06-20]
stl/lid_rear.stl
212.0 x 117.0 x 3.00

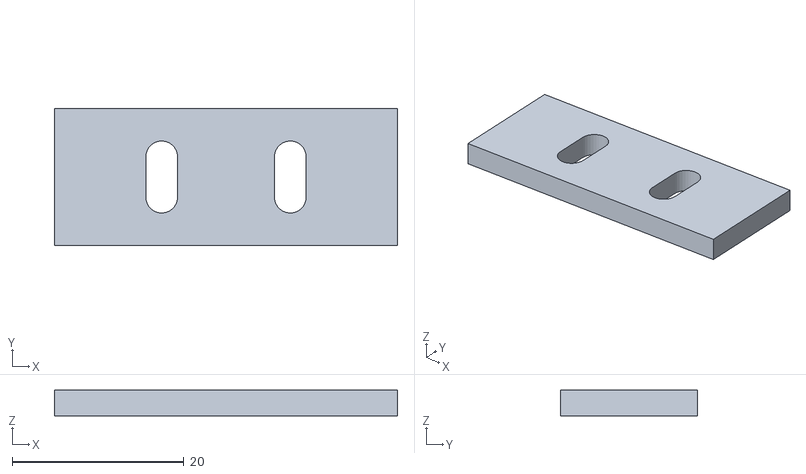
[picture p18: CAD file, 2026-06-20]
stl/seam_splice.stl
40.0 x 16.0 x 3.00

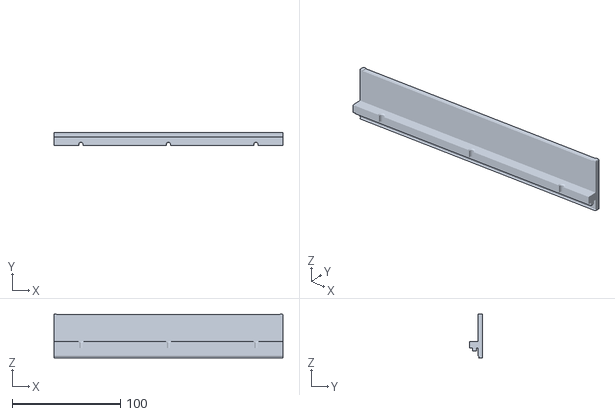
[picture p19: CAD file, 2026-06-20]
stl/rear_panel.stl
212.0 x 12.0 x 40.5

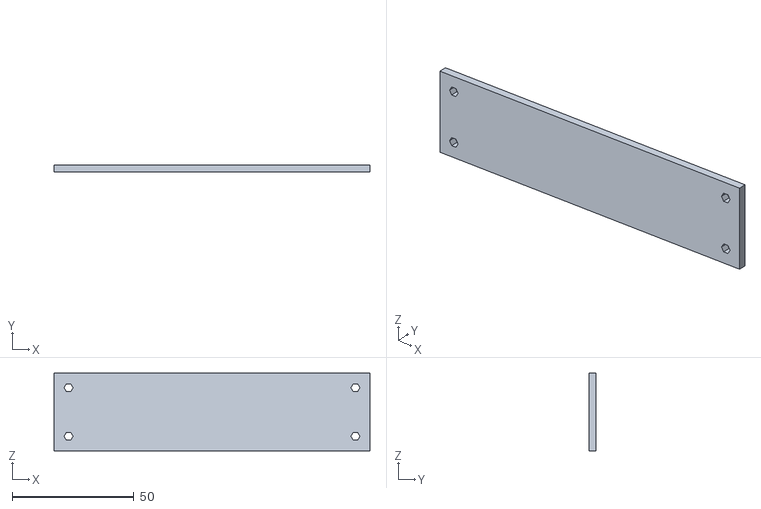
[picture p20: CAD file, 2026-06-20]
stl/io_subplate.stl
130.0 x 3.00 x 32.0

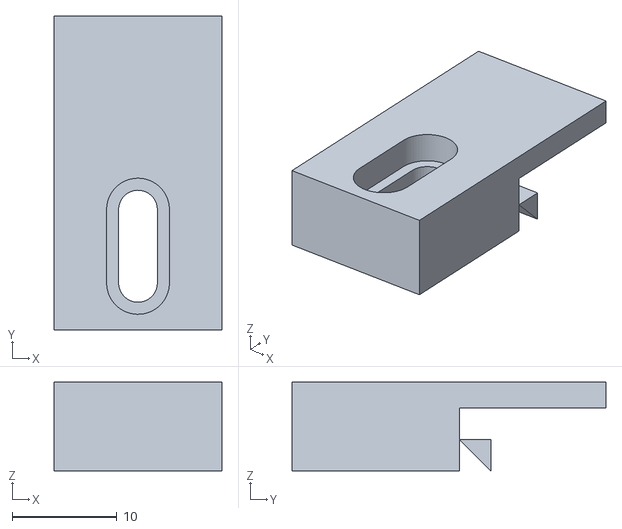
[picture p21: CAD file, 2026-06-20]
stl/board_edge_clip.stl
16.0 x 30.0 x 8.50

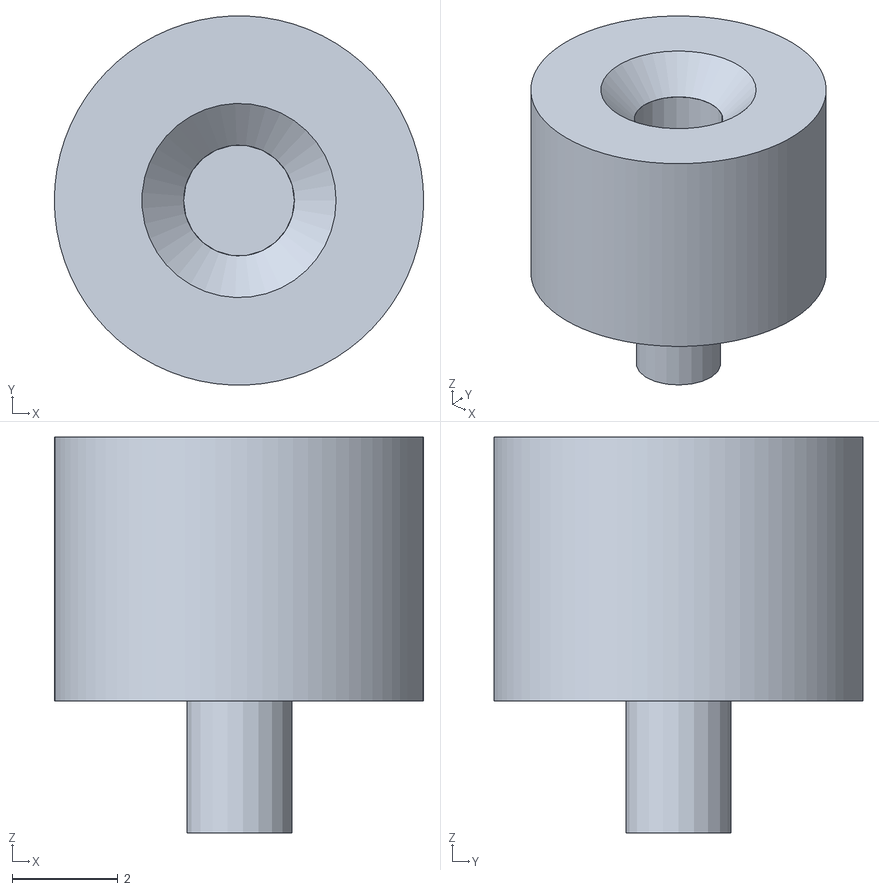
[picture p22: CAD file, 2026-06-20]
stl/m25_grid_insert.stl
7.00 x 6.99 x 7.50

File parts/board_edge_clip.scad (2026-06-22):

// =====================================================================
// parts/board_edge_clip.scad  ->  board_edge_clip()
//
// TOLERANCE-FIRST failsafe board retention. Bolts to a baseplate grid point
// and a finger reaches over the board's EDGE to clamp it down from above --
// so the board is held flat even if NONE of its mounting holes line up with
// the grid. Use ~4 (one per side/corner).
//
// The mount hole is SLOTTED (along Y) so you slide the clip in/out to press
// the board edge with light force before tightening -- forgiving of where the
// board edge actually sits (poor measurement) and of a loose printer.
//
// Modeled in its own local frame: foot at the origin, finger reaching +Y over
// the board edge. main.scad places/rotates one at each board edge. Prints flat
// on the bed (foot down), zero supports.
//
//   foot top (and finger underside) sit at the board top plane so the finger
//   lightly traps the PCB: BOARD_TOP = STANDOFF_H + BOARD_T above the floor.
// =====================================================================

include <params.scad>

module board_edge_clip(reach = 14) {
    foot_w   = 16;                         // foot width (X), spans a grid cell
    foot_d   = 16;                         // foot depth (Y)
    board_top = STANDOFF_H + BOARD_T;      // finger underside height above floor
    foot_h   = board_top + 2.5;            // foot rises a bit above the finger
    fing_t   = 2.5;                        // finger thickness (Z)
    slot_len = 7;                          // M3 slot travel (Y) for in/out adjust

    difference() {
        union() {
            // foot block (bolts to the grid)
            cube([foot_w, foot_d, foot_h]);
            // cantilever finger reaching over the board edge (+Y) at board-top
            // plane, so its underside lightly traps the PCB. A 45° gusset under
            // the root keeps the cantilever stiff and support-free.
            translate([0, foot_d - EPS, board_top])
                cube([foot_w, reach, fing_t]);
            // FULL-height 45° gusset: its vertical face fuses to the foot and
            // its top face meets the finger underside at board_top, so it
            // actually braces the cantilever AND self-supports the finger in
            // print (the old 3mm gusset stopped board_top-3 below the finger).
            translate([0, foot_d - EPS, board_top])
                rotate([0, 90, 0])
                    linear_extrude(foot_w)
                        polygon([[0,0],[board_top,0],[0,board_top]]);
        }
        // slotted M3 clearance hole through the foot, into the grid pilot below.
        // Slot runs in Y so the clip slides in/out before tightening.
        translate([foot_w/2, foot_d/2 - slot_len/2, -EPS])
            hull() {
                cylinder(h = foot_h + 2*EPS, d = M3_CLEAR);
                translate([0, slot_len, 0]) cylinder(h = foot_h + 2*EPS, d = M3_CLEAR);
            }
        // counterbore so the M3 head sits below the foot top (clears the board)
        translate([foot_w/2, foot_d/2 - slot_len/2, foot_h - 3])
            hull() {
                cylinder(h = 3 + EPS, d = M3_HEAD_D);
                translate([0, slot_len, 0]) cylinder(h = 3 + EPS, d = M3_HEAD_D);
            }
    }
}

// ---- standalone render ----
$fa = 2; $fs = 0.3;
board_edge_clip();

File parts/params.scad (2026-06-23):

// =====================================================================
// params.scad  —  FROZEN SHARED CONTRACT (global variables)
// Project: Dell Inspiron 15-5558/5559 motherboard -> NiH DIY 10" rack
// Printables #1634385 cage-nut rack. Printer: Ender 3 V3 SE. Material: PETG.
//
// GLOBAL ASSEMBLY COORDINATE FRAME (every part is modeled IN this frame;
// main.scad just unions modules with NO transforms):
//   Origin (0,0,0) = FRONT-BOTTOM-LEFT INTERIOR corner of the chassis body.
//   +X = width  (left  -> right)   structural body width 190mm  (X: 0..190)
//   +Y = depth  (front -> rear )   Y=0 is the RACK-FRONT interior face
//   +Z = height (bottom-> top  )   floor 0..FLOOR, interior up to 2U
//
// CONVENTION: include <params.scad> for these globals. Joinery modules in
// lib/joinery.scad are PARAMETRIC and do NOT read these globals — callers
// pass the values below in explicitly.
//
// Every uncertain real-world dimension is marked  // MEASURE  with a sane
// default so the model renders today; caliper later and update HERE only.
// =====================================================================


// ---------------------------------------------------------------------
// PRINTER / BED / PRINTABILITY LIMITS  (Ender 3 V3 SE)
// ---------------------------------------------------------------------
BED_X            = 220;     // bed size X (mm)
BED_Y            = 220;     // bed size Y (mm)
BED_Z            = 250;     // max print height (mm)
PRINT_MAX_XY     = 190;     // HARD design rule: every part <=190 in its two
                            //   bed-plane axes (prints flat with margin)
NOZZLE_D         = 0.4;     // nozzle diameter
LAYER_H          = 0.2;     // layer height
WALL_LINES       = 3;       // perimeters (target)
INFILL           = 0.30;    // 30% infill (target)
OVERHANG_MAX     = 45;      // deg; steeper requires chamfer/teardrop
EPS              = 0.01;    // epsilon overlap for boolean co-planar faces

// LOW-ACCURACY-PRINTER TOLERANCE — applied to EVERY mating feature so parts
// still bolt together when the printer is dimensionally loose / warps.
// "loose-fit, bolt-tight": gaps absorb slop, bolts pull seams flush.
FIT_CLEARANCE    = 0.5;     // per-side gap on all matings (slot/lap/dowel/insert fit)
CHAMFER          = 0.8;     // lead-in chamfer on holes/slots + bottom-edge relief
// (M3_SLOT_W is derived in the FASTENERS section below, after M3_CLEAR.)


// =====================================================================
// ★★★  YOUR BOARD  —  THE ONLY SECTION YOU EDIT FOR A DIFFERENT BOARD ★★★
// Drop in ANY laptop motherboard that fits a 10" rack: set its outline here
// and the whole chassis (body width, depth, the 4 baseplate quadrants, the
// faceplate centering, the grid) reflows automatically. Because the board is
// held by grid-placed standoffs + edge clips and the panels are BLANK
// drill-to-fit, you do NOT need exact hole/port positions — just the outline
// + a sane clearance. (Hole/port constants further down stay as // MEASURE
// hints for the optional reference board + pre-marked drill guides.)
// ---------------------------------------------------------------------
BOARD_W_X        = 203;     // board WIDTH  (X) = the rack-facing / I-O edge   // EDIT
BOARD_D_Y        = 197;     // board DEPTH  (Y) = I/O edge to the back         // EDIT
BOARD_T          = 1;       // board thickness (Z)                            // EDIT
STANDOFF_H       = 5;       // standoff height under the board (tallest part)  // EDIT
// Clearances the body adds around the board (rarely changed):
BOARD_MARGIN_X   = 4.5;     // X gap each side, board edge -> side wall
BOARD_FRONT_GAP  = 6;       // Y gap, rack-front face -> board front
BOARD_REAR_GAP   = 7;       // Y gap, board back -> rear panel
// Example boards — copy a line, then caliper to refine:
//   Dell Inspiron 15-5558/5559 : BOARD_W_X = 203; BOARD_D_Y = 197;   (default)
//   <your board here>          : BOARD_W_X = ___; BOARD_D_Y = ___;


// ---------------------------------------------------------------------
// CHASSIS BODY  (auto-sized from YOUR BOARD above; centered in the rack)
// ---------------------------------------------------------------------
BODY_W           = BOARD_W_X + 2*BOARD_MARGIN_X;   // structural body width (X)
FLOOR            = 3;       // floor / baseplate thickness (Z: 0..FLOOR)
WALL_T           = 3;       // integral side-wall upstand thickness (X walls)

// 10" rack fit guard — stops the build if the board is too big for a 10" rack:
RACK_MAX_BODY_W  = 216;     // ~usable width between the 10" rack rails
RACK_MAX_DEPTH   = 250;     // ~usable front-to-back depth of a 10" rack
assert(BODY_W <= RACK_MAX_BODY_W,
       str("Board too WIDE for a 10\" rack: body ", BODY_W,
           "mm exceeds ", RACK_MAX_BODY_W, "mm (max board width ~",
           RACK_MAX_BODY_W - 2*BOARD_MARGIN_X, "mm)."));

// --- 2U height ---
U_HEIGHT         = 44.45;   // 1U in mm (EIA-310)
N_U              = 1;       // chassis spans 1U (tallest board part ~8.9mm)
EXT_HEIGHT       = 44.45;   // external 1U height
UPSTAND_H        = 40;      // integral side-wall upstand height (lid sits on top: 40+3=43 < 44.45)
FACE_H           = 43.66;   // faceplate front-panel height (1U EIA panel, -0.79 binding margin)

// --- Depth + depth-split (auto from the board; seam near mid-depth) ---
DEPTH            = BOARD_FRONT_GAP + BOARD_D_Y + BOARD_REAR_GAP;  // interior depth (Y)
assert(DEPTH <= RACK_MAX_DEPTH,
       str("Board too DEEP for a 10\" rack: ", DEPTH, "mm exceeds ", RACK_MAX_DEPTH, "mm."));
LAP_LEN          = 25;      // overlap length of the rabbet lap (mm)
// Front quad depth: keep the EXACT original 110/125 split for the default Dell
// board (BOARD_D_Y==197); for any other board, derive a balanced mid-depth seam.
FRONT_TILE_D     = (BOARD_D_Y == 197) ? 110 : floor(DEPTH/2) + 8;
REAR_TILE_D      = DEPTH - FRONT_TILE_D + LAP_LEN; // rear quads span the remainder + lap
LAP_Y_NOMINAL    = FRONT_TILE_D;                   // seam centre / lap rear edge
LAP_STEP_Z       = FLOOR/2; // rabbet step height = half floor (1.5mm)


// ---------------------------------------------------------------------
// BOARD placement (derived from YOUR BOARD + the body; centered in X)
// ---------------------------------------------------------------------
BOARD_X0         = (BODY_W - BOARD_W_X) / 2;   // board centered in the body (= BOARD_MARGIN_X)
BOARD_Y0         = BOARD_FRONT_GAP;            // board front edge Y
BOARD_Z          = FLOOR + STANDOFF_H;         // board underside Z

// Board mounting holes [x,y] in ASSEMBLY frame (absolute, not board-local).
// 4 corners inset 8mm from board edges + 1 center.  ALL // MEASURE.
BOARD_HOLE_INSET = 8;       // MEASURE corner-hole inset from board edge
BOARD_HOLES = [             // MEASURE every coordinate below
    [BOARD_X0 + BOARD_HOLE_INSET,              BOARD_Y0 + BOARD_HOLE_INSET             ], // FL  ~[18, 10]
    [BOARD_X0 + BOARD_W_X - BOARD_HOLE_INSET,  BOARD_Y0 + BOARD_HOLE_INSET             ], // FR  ~[172,10]
    [BOARD_X0 + BOARD_HOLE_INSET,              BOARD_Y0 + BOARD_D_Y - BOARD_HOLE_INSET ], // RL  ~[18,229]
    [BOARD_X0 + BOARD_W_X - BOARD_HOLE_INSET,  BOARD_Y0 + BOARD_D_Y - BOARD_HOLE_INSET ], // RR  ~[172,229]
    [BOARD_X0 + 117.5,                         BOARD_Y0 + 85                           ]  // CTR ~[127.5,87] MEASURE
];


// ---------------------------------------------------------------------
// RACK INTERFACE (faceplate)  —  NiH DIY 10" cage-nut rack
//   External faceplate spans full 254mm rack width, centered on body
//   center X=95 => faceplate X from -32 .. 222.  Split at X=95 into
//   left tile (X -32..95) and right tile (X 95..222), each 127 wide.
// ---------------------------------------------------------------------
BODY_CX          = BODY_W / 2;        // = 95  (faceplate & rack centerline)
FACE_W           = 254;               // full faceplate width (X span)
FACE_T           = 4;                 // faceplate thickness (Y), at Y -FACE_T..0
FACE_X0          = BODY_CX - FACE_W/2;// = -32  (faceplate left edge)
FACE_X1          = BODY_CX + FACE_W/2;// = 222  (faceplate right edge)
FACE_SPLIT_X     = BODY_CX;           // = 95   (left|right tile seam)
FACE_TILE_W      = FACE_W / 2;        // = 127  (each tile width)

// --- M5 rack cage-nut columns (CLEARANCE holes, NOT inserts) ---
M5_SPACING       = 236.525;           // center-to-center of the two columns
M5_X_LEFT        = BODY_CX - M5_SPACING/2;  // = -23.2625  (left column)
M5_X_RIGHT       = BODY_CX + M5_SPACING/2;  // = 213.2625  (right column)
// each column sits 8.74mm inside its tile's OUTER edge so each rack column
// is WHOLE on one tile:  -23.2625 - (-32) = 8.7375 ;  222 - 213.2625 = 8.7375
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

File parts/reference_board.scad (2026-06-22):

// =====================================================================
// parts/reference_board.scad  ->  reference_board()
//
// VISUAL REFERENCE ONLY — a recognizable Dell Inspiron 15-5558/5559
// laptop motherboard prop. NEVER printed, never sliced. It sits inside
// the case in the assembly + exploded renders and in the README, so a
// faithful, DENSE, photo-accurate SILHOUETTE matters far more than
// electrical accuracy.
//
// STYLE: DENSE + REALISTIC. A busy, populated board — full VRM section
// (MOSFET arrays + inductors + cap banks), big PCH + EC chips, many
// small passives, refined connectors with metal shells/throats and gold
// contacts, dual (forked) heatpipe, blower fan with a volute/scroll
// housing + skewed blades + label, individual heatsink fins, an X spring
// bracket over the CPU/GPU plate, populated SODIMM + M.2 + WLAN, SATA FFC
// connector, board mounting-hole ring pads, and the characteristic
// rear-left notch in the PCB outline.
//
// BOARD-LOCAL COORDINATE FRAME (main.scad 'use's this file and places it
// at the board datum, so everything here is board-local):
//   PCB occupies  X 0..BOARD_W_X (=203, width)
//                 Y 0..BOARD_D_Y (=197, depth)   Y=0 = FRONT (rack I/O)
//                 Z 0..BOARD_T   (~1, the PCB slab)
//   ALL components sit ON TOP, growing +Z from Z=BOARD_T.
//
// Colors are applied per-feature with color("#hex").  params.scad
// supplies BOARD_W_X / BOARD_D_Y / BOARD_T only.
// =====================================================================

include <params.scad>

// ---- local palette ---------------------------------------------------
PCB_COL      = "#16386e";
PIPE_COL     = "#b87333";
METAL_COL    = "#bfc4c8";   // heatsink / fins / plate
FAN_COL      = "#2c2f33";   // fan volute housing
HUB_COL      = "#17191c";   // fan hub
RAM_COL      = "#2e7d32";   // green DIMM / M.2 card
SLOT_COL     = "#15171a";   // black sockets
CONN_COL     = "#9aa0a6";   // metallic connector shells
COIN_COL     = "#d0d3d6";   // CMOS coin cell
CHIP_COL     = "#0e0f12";   // black SMD chips
// ---- extended palette (new) -----------------------------------------
GOLD_COL     = "#c9a23a";   // gold edge contacts / fingers
IND_COL      = "#222428";   // chunky VRM inductor blocks
CAP_TAN_COL  = "#b8860b";   // tantalum / electrolytic caps
CAP_ALU_COL  = "#3a3f45";   // aluminum can caps
PAD_COL      = "#c7ccd0";   // silver ring pad around mounting holes
LABEL_COL    = "#eceff1";   // white fan label
STEEL_COL    = "#7d8388";   // spring bracket / latches
LATCH_COL    = "#8a9096";   // SODIMM retention latch arms

ZTOP = BOARD_T;             // everything grows up from here

// =====================================================================
// COMPONENT PLACEMENT CONSTANTS  (board-local, all inside 0..203 X,
// 0..197 Y).  Retune HERE — every module reads these, nothing hardcoded.
// Datum reminders:  Y=0 = FRONT (rack I/O) ;  Y=BOARD_D_Y = REAR.
// =====================================================================

// --- 2. BLOWER FAN ---  (front-right, exhaust snout points -Y toward fins)
BLOWER_CX    = 150;         // fan center X
BLOWER_CY    = 52;          // fan center Y (near front)
BLOWER_RO    = 34;          // outer fan radius (enlarged from 30)
BLOWER_H     = 14;          // fan height

// --- 3. HEATSINK FINS ---  (radiator at the FRONT edge, exhaust faces -Y)
FINS_X0      = 116;         // fin block X span...
FINS_X1      = 184;
FINS_Y0      = 2;           // ...sits at the very front edge (Y near 0)
FINS_Y1      = 18;
FINS_H       = 12;

// --- 4. HEATPIPE ---  copper waypoint chain: CPU/GPU plate -> blower.
//   First point sits on the plate (rear), last point at the fan/fins.
HEATPIPE_PTS = [
    [ 78, 150], [ 96, 132], [118, 110],
    [134,  86], [146,  68], [150,  54]
];
// SECOND (forked) branch — GPU branch splits off near the plate and runs
// a short way before merging visually back toward the fan.
HEATPIPE_FORK = [
    [ 78, 150], [ 92, 158], [108, 154], [124, 132], [140, 104]
];
HEATPIPE_R   = 4;           // pipe radius (~D8)

// --- 5. CPU/GPU HEATSINK PLATE ---  (mid/rear of the board)
PLATE_X0     = 58;
PLATE_Y0     = 128;
PLATE_X1     = 122;
PLATE_Y1     = 176;
PLATE_H      = 3;

// --- 5b. VRM / POWER SECTION ---  cluster next to the plate/fan
VRM_X0       = 120;
VRM_X1       = 168;
VRM_Y0       = 150;
VRM_Y1       = 192;

// --- 6. SODIMM SLOTS ---  two stacked slots, run along X.  X 20..150.
SODIMM_X0    = 20;
SODIMM_X1    = 150;
SODIMM1_Y0   = 96;          // slot 1 (populated)
SODIMM1_Y1   = 104;
SODIMM2_Y0   = 110;         // slot 2 (empty)
SODIMM2_Y1   = 118;

// --- 7. DRAM CHIP ROW ---  open area, front-center
DRAM_Y       = 78;
DRAM_X0      = 64;          // first chip center X
DRAM_DX      = 22;          // chip-to-chip X pitch

// --- 8. M.2 / NGFF SSD ---  connector rear-right, card lies toward -X
M2_CONN_X0   = 150;
M2_CONN_X1   = 158;
M2_CONN_Y0   = 158;
M2_CONN_Y1   = 166;
M2_CARD_X0   = 70;          // card far end
M2_CARD_Y    = 162;         // card centerline Y

// --- 9. WLAN NGFF ---  small slot, rear-left
WLAN_SLOT_X0 = 36;
WLAN_SLOT_X1 = 44;
WLAN_SLOT_Y0 = 182;
WLAN_SLOT_Y1 = 186;
WLAN_CARD_X0 = 18;          // tiny card extends toward -X
WLAN_CARD_X1 = 36;
WLAN_CARD_Y  = 184;

// --- 10. COIN CELL (CMOS) ---  rear-right open corner
COIN_CX      = 186;
COIN_CY      = 178;

// --- 10b. SATA FFC CONNECTOR ---  rear-left/left edge, feeds 2.5" SSD
SATA_X0      = 6;
SATA_X1      = 30;
SATA_Y0      = 144;
SATA_Y1      = 156;

// --- 10c. MOUNTING HOLES ---  4 corners (inset 10) + 1 near center
HOLE_INSET   = 10;
MOUNT_HOLES = [
    [HOLE_INSET,             HOLE_INSET            ],   // FL
    [BOARD_W_X - HOLE_INSET, HOLE_INSET            ],   // FR
    [HOLE_INSET,             BOARD_D_Y - HOLE_INSET],   // RL
    [BOARD_W_X - HOLE_INSET, BOARD_D_Y - HOLE_INSET],   // RR
    [BOARD_W_X/2 + 4,        BOARD_D_Y/2 - 6       ]    // CTR-ish
];
HOLE_R       = 1.75;        // ~D3.5
PAD_R        = 3.2;         // silver ring-pad outer radius

// --- PCB rear-left NOTCH ---  stepped bite out of the slab silhouette
NOTCH_X0     = 0;
NOTCH_X1     = 28;
NOTCH_Y0     = 179;
NOTCH_Y1     = 197;

// --- 11. FRONT-EDGE I/O ---  (Y near 0) HDMI + RJ45 + USB-A x2, spread X.
IO_DEPTH     = 14;          // how far the connector stack reaches in +Y
HDMI_X0      = 14;   HDMI_X1  = 32;     // HDMI
RJ45_X0      = 44;   RJ45_X1  = 64;     // RJ45
USBA1_X0     = 78;   USBA1_X1 = 92;     // USB-A #1
USBA2_X0     = 100;  USBA2_X1 = 114;    // USB-A #2
DISP_X0      = 172;  DISP_X1  = 196;    // display/power connector (black)

// --- 12. REAR-EDGE I/O ---  (Y near BOARD_D_Y) USB-C + SD + audio
USBC_X0      = 30;   USBC_X1  = 44;
SD_X0        = 92;   SD_X1    = 116;
AUDIO_CX     = 188;                     // 3.5mm audio jack barrel center X

// ---------------------------------------------------------------------
// small helpers (UNCHANGED signatures)
// ---------------------------------------------------------------------

// rounded-rectangle prism sitting on its base at z0, extruded h in +Z
module rrect_prism(x0, y0, x1, y1, z0, h, r=1.2) {
    w = x1 - x0; d = y1 - y0;
    rr = min(r, w/2 - 0.01, d/2 - 0.01);
    translate([x0, y0, z0])
        linear_extrude(height = h)
            offset(r = rr) offset(delta = -rr)
                square([w, d]);
}

// plain axis-aligned box from two corners
module box2(x0, y0, x1, y1, z0, h) {
    translate([x0, y0, z0]) cube([x1 - x0, y1 - y0, h]);
}

// a chip: rounded black SMD body on small standoff so it reads as a part
module smd_chip(cx, cy, sx, sy, h=1.4) {
    color(CHIP_COL)
        rrect_prism(cx - sx/2, cy - sy/2, cx + sx/2, cy + sy/2, ZTOP, h, r=0.5);
}

// ---------------------------------------------------------------------
// NEW small helpers (texture / passives)
// ---------------------------------------------------------------------

// little MLCC / resistor passive: tiny tan or grey chip
module passive_0805(cx, cy, col="#cdb892") {
    color(col)
        rrect_prism(cx - 1.0, cy - 0.6, cx + 1.0, cy + 0.6, ZTOP, 0.7, r=0.2);
}

// tantalum / electrolytic cap can
module cap_can(cx, cy, r=1.6, h=3.5, col=CAP_TAN_COL) {
    color(col) translate([cx, cy, ZTOP]) cylinder(h = h, r = r);
    // marked + stripe on top
    color("#1a1a1a")
        translate([cx, cy, ZTOP + h]) cylinder(h = 0.3, r = r*0.55);
}

// VRM MOSFET (small black square package with a silver tab hint)
module mosfet(cx, cy, s=4) {
    color(CHIP_COL)
        rrect_prism(cx - s/2, cy - s/2, cx + s/2, cy + s/2, ZTOP, 1.6, r=0.4);
    color(METAL_COL)
        box2(cx - s/2, cy + s/2 - 0.6, cx + s/2, cy + s/2, ZTOP, 1.7);
}
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

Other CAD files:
stl/baseplate_FR.stl
stl/baseplate_RR.stl
main.scad
parts/baseplate.scad
parts/faceplate_left.scad
parts/faceplate_right.scad
parts/io_subplate.scad
parts/lid.scad
parts/m25_grid_insert.scad
parts/m2_retainer.scad
parts/rear_panel.scad
parts/ssd_mezzanine.scad

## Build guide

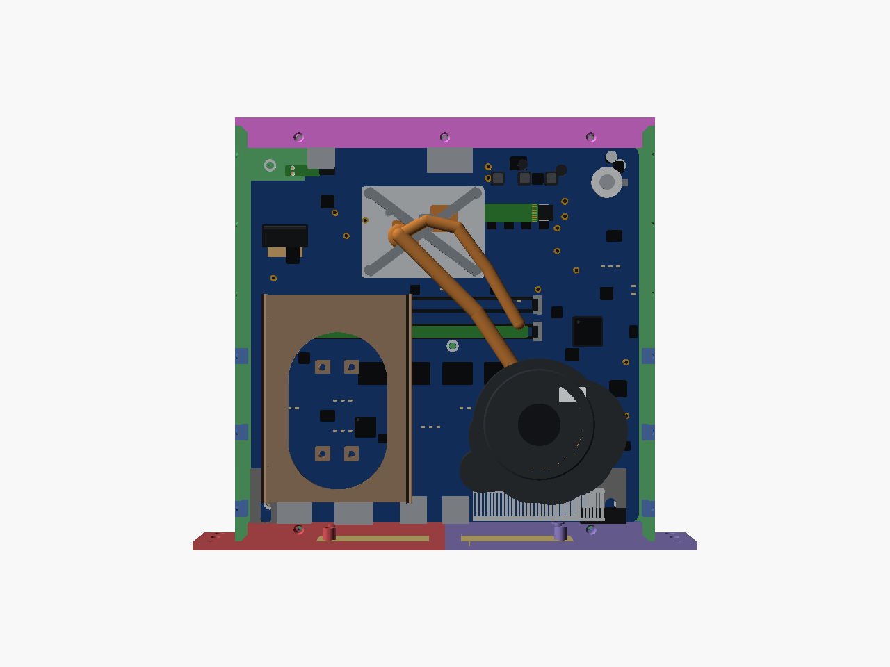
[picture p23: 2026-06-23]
docs/img/assembly_top.png

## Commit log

2026-06-20 feat: modular 2U OpenSCAD case for Dell 5558 board in a 10" rack
    Parametric, Ender 3 V3 SE-printable enclosure that mounts a salvaged
    Dell Inspiron 15-5558/5559 motherboard into a NiH 10" cage-nut rack.
    - 9 independently-printable modules on one 15mm M3 self-tap pilot grid
    - 2-tile baseplate (bolted rabbet-lap) + centerline-split faceplate so
    every part fits the 220x220 bed flat and support-free
    - supplies the board's missing M.2 standoff; swappable front I/O subplate
    - shared contract in parts/params.scad (board dims tagged // MEASURE)
    - reusable joinery in lib/joinery.scad
    [baseplate_front.scad, baseplate_rear.scad, faceplate_left.scad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]
2026-06-20 feat: recognizable reference board model + colored, labeled renders
    - parts/reference_board.scad: visual-only Dell 5558 board prop (blower,
    curved heatpipe, finned heatsink, X-bracket, RAM, M.2, coin cell, edge
    I/O) shown inside the case in the renders; never printed
    - main.scad: place the board on the standoff plane; give every part a
    distinct color for visual separation
    - docs/img: re-render iso/exploded in the new palette + add interior view,
    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
    [main.scad, reference_board.scad]
2026-06-20 refactor(params): 1U heights + 203x197 footprint + FIT_CLEARANCE
    - 2U->1U: N_U=1, EXT_HEIGHT=44.45, UPSTAND_H=40, decoupled FACE_H=43.66
    (faceplate panel taller than interior walls); EIA holes auto 6->3.
    - New ~square board footprint: BOARD 203x197x1; BODY_W=212, DEPTH=210,
    BODY_CX=106 (faceplate + M5 columns cascade); grid 13x13.
    - I/O block shrunk to fit 1U (IO_SUB_H=32, window 6..38); blank default.
    - Low-accuracy-printer tolerance: FIT_CLEARANCE=0.5, CHAMFER, M3_CLEAR 3.4->3.7,
    M3_SLOT_W for forgiving slotted seams.
    - Wire faceplate_left/right to the 1U FACE_H.
    [faceplate_left.scad, faceplate_right.scad, params.scad]
2026-06-20 feat: tolerance-first board mounting (grid standoff + edge clip)
    Accept a poorly-measured board without exact hole coords:
    - m25_grid_insert: a small printed M2.5 standoff that drops into ANY 15mm
    grid pilot (locating peg + blind M2.5 self-tap bore). Place at the nearest
    grid point to each real board hole -> automatic +/-7.5mm tolerance.
    - board_edge_clip: bolts to a grid point, a gusseted finger clamps the board
    edge from above; slotted M3 hole gives in/out adjustment so it holds the
    board even if NO hole aligns. All loose-fit + chamfered for a low-accuracy
    printer.
    [board_edge_clip.scad, m25_grid_insert.scad]
2026-06-20 feat(baseplate): split floor into 4 bed-friendly quadrants
    - New parts/baseplate.scad: model the full floor (walls + panel lips + 15mm
    self-tap grid, NO fixed standoffs) once, then clip into 4 quadrants
    (~106x110x40 each) that print flat with no warp on a low-accuracy printer.
    - Quadrants butt and are tied by flat seam_splice() bars that bolt into grid
    pilots across each seam (slotted = forgiving). Bottom-edge chamfer for
    elephant-foot relief.
    - Retire baseplate_front/rear.scad; main.scad assembles the 4 quads + splices
    with X/Y explode.
    [baseplate.scad, baseplate_front.scad, baseplate_rear.scad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]
2026-06-20 feat(io): blank io_subplate default + looser dovetail fit
    - io_subplate IO_VARIANT="blank" (tolerance default): solid insert the user
    drills once ports are measured, then reprints just this cheap part. Port
    cutouts only render for the measured variants.
    - faceplate_right dovetail female clearance -> FIT_CLEARANCE (loose printer).
    - NOTE: faceplate centerline dovetail seam is still 2U-proportioned and
    overshoots the 1U panel; needs a bolted-overlap rework (remaining).
    [faceplate_left.scad, faceplate_right.scad, io_subplate.scad]
2026-06-20 chore: rename reference images (photo-*/boardview-*) + commit boardviews
    - motherboard-{1,2}.jpeg -> photo-{1,2}.jpeg; add the LA-B843P/LA-D071P
    boardview screenshots as boardview-{1,2}.png (un-ignored).
    - README points at photo-1.jpeg.
2026-06-20 feat(faceplate): replace dovetail with bolted-overlap 1U seam
    Centerline seam now fits the 1U panel exactly (Zmax=FACE_H=43.66) and is a
    forgiving bolted overlap (lap tongue + 2 M3 slotted holes + chamfer lead-ins)
    instead of the brittle 2U-proportioned dovetail. Both tiles render Simple:yes.
    [faceplate_left.scad, faceplate_right.scad]
2026-06-20 feat: blank rear panel + above-board SSD mezzanine
    - rear_panel: blank 1U closure (USB-C/SD/audio drilled later).
    - ssd_mezzanine: 2.5" SATA tray on grid standoffs ABOVE the board (1U has
    ~27mm clearance), clears the blower; replaces the floor-bound ssd_cage.
    - main.scad: wire ssd_mezzanine + a SHOW_MOUNTS illustration of the grid
    standoffs/edge clips; remove ssd_cage.
    [main.scad, rear_panel.scad, ssd_cage.scad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]
2026-06-20 fix(reference-board): rewrite for 203x197, front I/O, fixed turrets
    Parameterize every component; rescale to the near-square board; move the
    blower + heatsink fins to the FRONT edge (exhaust faces the rack front);
    add RJ45 to the front I/O cluster (HDMI+RJ45+USB); fix the X-bracket screw
    turrets that flew off-board. Renders cleanly (visual-only prop).
    [reference_board.scad]
2026-06-20 docs: refresh README + CASE_DESIGN + renders for the 1U Round-2 design
    1U / near-square board / 4-quadrant baseplate / tolerance-first mounting /
    loose-fit-bolt-tight joinery / blank panels / ssd mezzanine. Re-rendered
    iso, exploded, interior, reference-board, and baseplate-grid images.
2026-06-20 docs: regenerate labeled exploded diagram for the 1U 4-quadrant design
    Updates the legend/colors to match Round-2 (4 baseplate quadrants, seam
    splices, blank io/rear panels, ssd_mezzanine). All README images now current.
2026-06-20 feat: add stl/ printable exports + export_stl.sh
    - export_stl.sh regenerates every printable part to stl/ (run after editing
    params.scad). 15 parts, all Simple:yes; reference_board (visual prop) excluded.
    - stl/README.md documents the print order (test-print a clip first, then the
    4 baseplate quadrants, splices/inserts/clips, panels, optional mezzanine/lid)
    and PETG/brim settings for a low-accuracy printer.
    - .gitignore: un-ignore stl/*.stl so the prototype exports ship with the repo.
2026-06-20 fix(gitignore): un-ignore stl/*.stl (inline comment broke the rule)
    Adds the 15 exported prototype STLs that the previous commit missed.
    [baseplate_FL.stl, baseplate_FR.stl, baseplate_RL.stl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]
2026-06-20 docs: show how the 4 baseplate quadrants connect via seam splices
    - Add docs/img/baseplate_assembly.png: the 4 quadrants forming one floor with
    red seam_splice bars bolted across both seams (the splices were previously
    invisible in every preview - hidden under the board, suppressed in exploded).
    - README: embed it next to the quadrant/grid description.
    - main.scad: add the Y-seam splices too (X+Y) for a complete model.
    [main.scad]
2026-06-20 docs: add SLICING.md (Ender 3 V3 SE / PETG slicer profile)
    Temps, quality, speed, cooling, retraction (Sprite direct drive), brim,
    no-supports, and the design-specific tolerance settings (XY/hole expansion = 0
    since FIT_CLEARANCE handles slop) + per-part notes. Linked from README + stl/.
2026-06-20 docs: add PETG filament estimate (~405 g core, ~565 g full)
    Per-part table computed from the exported STL volumes (near-solid estimate,
    ~10% high vs 30% infill). Core case ~40% of a 1kg spool; full set ~55%.
2026-06-22 docs: add rough print-time estimate to SLICING.md
    ~30-40h core / ~45-55h full set at the guide's PETG speeds (10-14 g/hr);
    baseplate quadrants dominate; faster speeds cut ~30-40%.
2026-06-22 docs(readme): polish — badges, jump-nav, print stats, balanced comparison
    - Add license/CAD/form-factor/print badges + a one-line tagline + a jump-nav.
    - New 'Print it' section (filament ~405-565 g, ~30-55 h, settings) linking stl/
    and SLICING.md.
    - Fix the lopsided donor-vs-model comparison: HTML table with both images sized
    to 430 px (was a markdown table rendering them at native size).
    - Drop the now-incorrect 'labeled legend is stale' note (it was regenerated).
2026-06-22 feat(reference-board): much more detailed + photo-accurate model
    Chosen from a 3-candidate diverse panel (accuracy/density/balanced -> density).
    Added vs the prior model:
    - dual forked CPU+GPU heatpipe; enlarged blower w/ spec label + visible blades
    - VRM/MOSFET power section (MOSFET arrays + inductors + cap bank) by the fan
    - SATA FFC ribbon connector on the left edge; 5 ringed board mounting holes
    - SODIMM metal retention latch arms; notched (rear-left) PCB outline
    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
    [reference_board.scad]
2026-06-22 feat(params): make the case parametric for any rack-fitting laptop board
    Add a '★ YOUR BOARD' block at the top of params.scad — set BOARD_W_X/D_Y/T +
    STANDOFF_H and the body width, interior depth, the 4 baseplate quadrants,
    faceplate centering, and the grid all reflow automatically. Adds 10"-rack-fit
    asserts (max board ~207mm wide x ~237mm deep). The Dell default is pinned to
    the original 110/125 split, so it is byte-identical for that board.
    [params.scad]
2026-06-22 docs: rename project to 'lazarack' + reframe for any laptop board
    - README: new title/tagline (lazarack = Lazarus + rack), parametric framing
    (any laptop board, Dell 5558 as the worked example), a 'Use it for a
    different board' section, parametric badge, updated jump-nav.
    - CASE_DESIGN: generic + parametric intro.
    - GitHub repo renamed dell-5558-rack-mount -> lazarack.
2026-06-22 test: add OpenSCAD unit suite + GitHub Actions CI
    tests/run_tests.sh renders every part headless and asserts: no render
    errors / failed asserts, 2-manifold geometry, bed-fit, parametric
    invariants (Dell default derives BODY_W=212/DEPTH=210/split 110-125),
    and that the rack-fit asserts reject oversized boards + accept valid
    ones. Portable to bash 3.2 (macOS) and bash 5 (CI). CI installs OpenSCAD
    + Xvfb on ubuntu and runs the suite on every push/PR.
2026-06-22 fix(joinery): resolve 9 mating defects found in the joinery review
    A multi-agent review traced every seam/flange; these 9 (8 high, 1 med) were
    adversarially confirmed (3 false positives dropped). Fixes:
    - params: add a SHARED panel-lip + lid-fastener contract (LIP_*, PANEL_PILOT_X,
    FRONT/REAR_PILOT_Y, LID_FASTEN_Y_*) so mating parts can't drift apart.
    - main: snap X-seam (and Y-seam) splice bars so every bolt lands on a real grid
    pilot (they previously came down on bare floor, 4.5-5.5mm off).
    - faceplate L/R: flange now RESTS ON the front lip and bolts straight DOWN into
    the shared pilots (was a floor-tongue that rammed the solid lip and bolted
    into nothing; right tile's horizontal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
    [baseplate.scad, board_edge_clip.scad, faceplate_left.scad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]
2026-06-22 docs: regenerate renders + document the joinery fixes
    - Regenerate all assembly/baseplate renders (exploded view now shows the
    4-tile lid); add reproducible render_docs.sh.
    - README + CASE_DESIGN: lid is 4 tiles into wall-top bosses; faceplate/rear
    flanges rest on the lip + bolt into shared pilots; bed-fit note updated.
2026-06-23 fix(joinery): harden lid-fastener reflow + flange wall clearance
    From the post-fix ultracode review (3 confirmed, all low-confidence):
    - PR-1/PR-2: LID_FASTEN_Y_FRONT/REAR used fixed offsets that went
    non-monotonic / merged / ran off-chassis for boards much shallower than a
    laptop board. Re-derive both trios at 0.15/0.5/0.85 across EACH quad's own
    depth (clamped by the boss half-width) so they stay ordered + non-overlapping
    for any depth, and add a loud min-depth assert (rear quad >= 3*LID_BOSS_Y).
    Dell default is unaffected in fit (Ys now [16.5,55,93.5] / [125,160,195]).
    - F2: faceplate + rear-panel flanges butted the side-wall inner faces at ZERO
    clearance (violating the FIT_C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
    [faceplate_left.scad, faceplate_right.scad, params.scad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]
2026-06-23 fix(docs): regenerate doc renders to match main's geometry
    PR #4's render commit (40877f9) was orphaned — gh pr merge ran against the
    cached PR head (ac366c5, code-only) right after the image commit was pushed,
    so the merge's 2nd parent was the pre-render commit. The committed
    baseplate_grid.png was a stale wrong-camera (edge-on) render instead of the
    top-down pilot-grid view; the rest were pre-hardening (sub-visible). All 7
    regenerated from the current main geometry via render_docs.sh.
